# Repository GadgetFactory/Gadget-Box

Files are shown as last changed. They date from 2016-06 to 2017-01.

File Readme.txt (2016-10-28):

GadgetBox tackles the biggest problems with current IoT devices – shield stacking, easily adding hardware, hardware compatibility, and an enclosure for your project. There are lots of IoT hardware options out there but none of them have thought the problem all the way through, so what we end up with is either a crazy tower of shields or peripherals soldered on with jumper wires. Not something we can proudly show our friends and family, let alone put into use in our homes.

GadgetBox starts with a case and builds from there – so the end result is an attractive, functional device with all of the electronics safely contained in the case.

Inside the GadgetBox case is a motherboard that provides all of the circuitry to charge and use a Lipo battery pack, provide higher current to your peripherals, and organizes all IO pins into the Universal eCog scheme. A motherboard for all of the most popular IoT devices is currently in the works – Arduino, Teensy, Pi Zero, ESP8266, etc.

eCogs are Universal peripherals that just snap into the motherboard and form the top of your enclosure. Only the hardware that is needed by the end user is exposed to the outside world, everything else is tucked inside the enclosure. Because the motherboards are designed using the Universal eCog scheme you can freely interchange your eCogs between motherboards. If you have an SD card eCog shouldn’t you be able to use that same eCog with the Arduino, Teensy, Pi Zero, and ESP8266? Of course you should, the Universal eCog scheme makes that possible.

Learn more at:
https://hackaday.io/project/12426-gadgetbox-no-more-shield-stacking-or-ugly-wires
http://GadgetBox.GadgetFactory.net

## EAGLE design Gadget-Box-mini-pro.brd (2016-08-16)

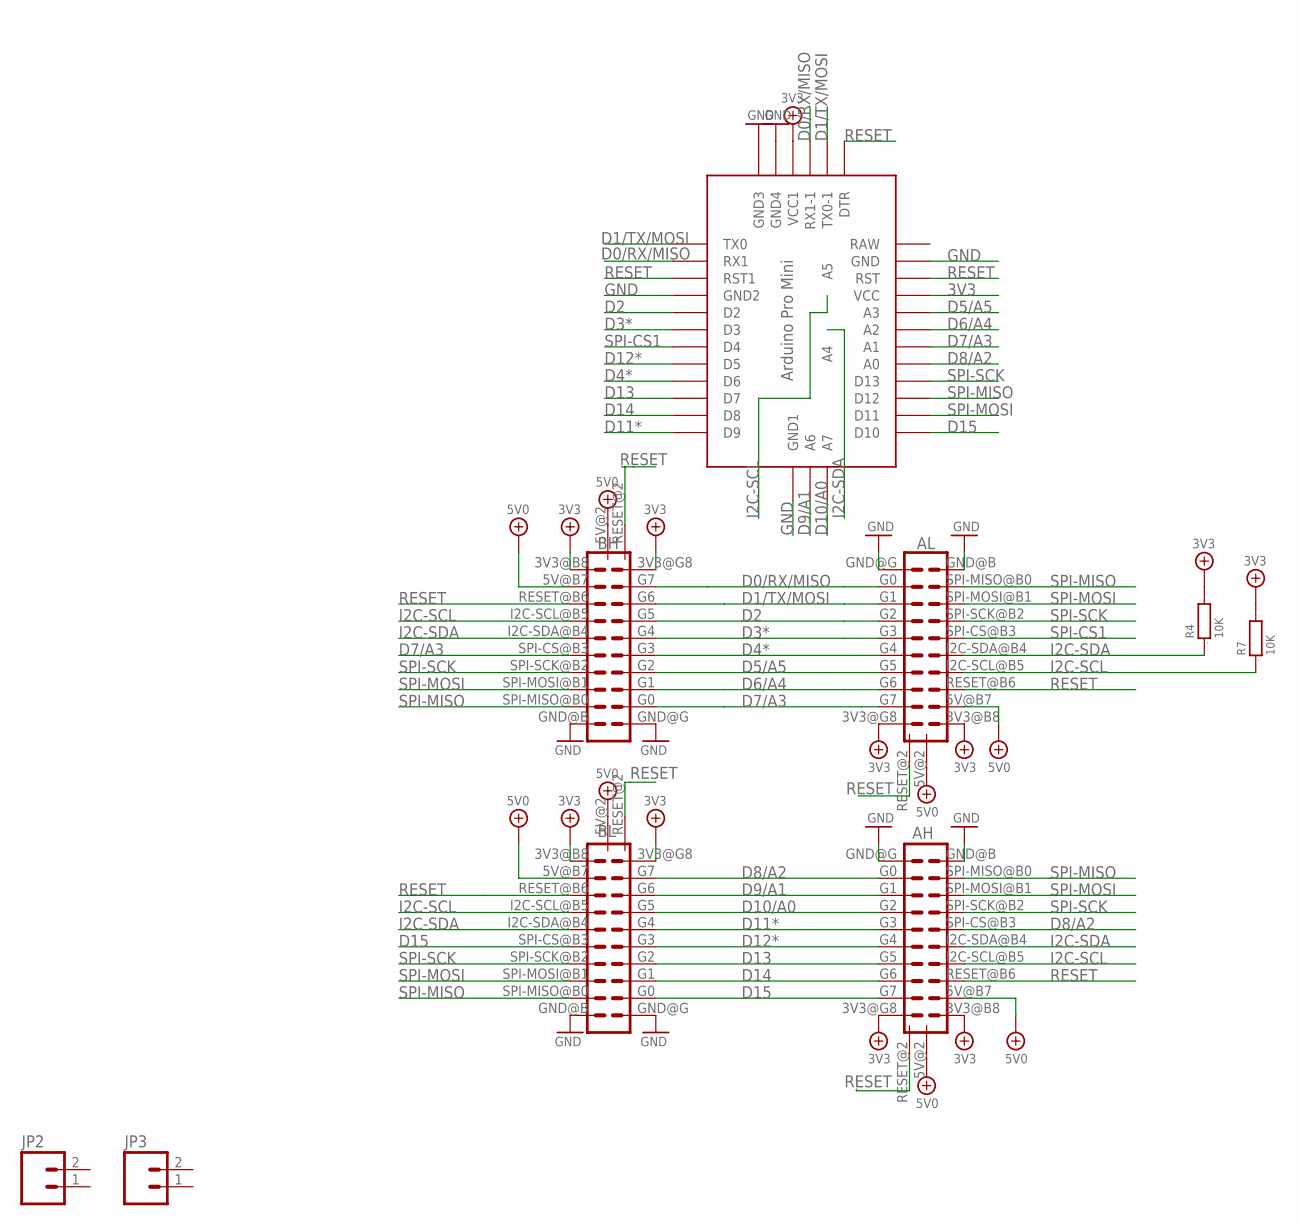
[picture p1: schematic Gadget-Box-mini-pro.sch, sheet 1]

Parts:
AH: ECOGECOG_SLOT_ALT1; ECOG_ALT1; PARTNO PPPC102LFBN-RC,SULLINS CONNECTOR SOLUTI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
AL: ECOGECOG_SLOT_ALT1; ECOG_ALT1; PARTNO PPPC102LFBN-RC,SULLINS CONNECTOR SOLUTI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
BH: ECOGECOG_SLOT_ALT1; ECOG_ALT1; PARTNO PPPC102LFBN-RC,SULLINS CONNECTOR SOLUTI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
BL: ECOGECOG_SLOT_ALT1; ECOG_ALT1; PARTNO PPPC102LFBN-RC,SULLINS CONNECTOR SOLUTI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
JP2, JP3: M021X02_NO_SILK; 1X02_NO_SILK
R4, R7: 10K; 0805
U$1: ABK-PRO-MINI

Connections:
3V3: AH.3V3@B8 (3V3), AH.3V3@G8 (3V3), AL.3V3@B8 (3V3), AL.3V3@G8 (3V3), BH.3V3@B8 (3V3), BH.3V3@G8 (3V3), BL.3V3@B8 (3V3), BL.3V3@G8 (3V3), R4.2, R7.2, U$1.VCC, U$1.VCC1; also elsewhere on the board
5V0: AH.5V@2 (5V), AH.5V@B7 (5V), AL.5V@2 (5V), AL.5V@B7 (5V), BH.5V@2 (5V), BH.5V@B7 (5V), BL.5V@2 (5V), BL.5V@B7 (5V); also elsewhere on the board
D0/RX/MISO: AL.G0, BH.G7, U$1.RX1, U$1.RX1-1
D1/TX/MOSI: AL.G1, BH.G6, U$1.TX0, U$1.TX0-1
D2: AL.G2, BH.G5, U$1.D2
D3*: AL.G3, BH.G4, U$1.D3
D4*: AL.G4, BH.G3, U$1.D6
D5/A5: AL.G5, BH.G2, U$1.A3; also elsewhere on the board
D6/A4: AL.G6, BH.G1, U$1.A2
D7/A3: AL.G7, BH.G0, BH.SPI-CS@B3 (SPI-CS), U$1.A1
D8/A2: AH.G0, AH.SPI-CS@B3 (SPI-CS), BL.G7, U$1.A0
D9/A1: AH.G1, BL.G6, U$1.A6
D10/A0: AH.G2, BL.G5, U$1.A7
D11*: AH.G3, BL.G4, U$1.D9
D12*: AH.G4, BL.G3, U$1.D5
D13: AH.G5, BL.G2, U$1.D7
D14: AH.G6, BL.G1, U$1.D8
D15: AH.G7, BL.G0, BL.SPI-CS@B3 (SPI-CS), U$1.D10
GND: AH.GND@B (GND), AH.GND@G (GND), AL.GND@B (GND), AL.GND@G (GND), BH.GND@B (GND), BH.GND@G (GND), BL.GND@B (GND), BL.GND@G (GND), U$1.GND, U$1.GND1 (GND2), U$1.GND2 (GND3), U$1.GND3 (GND4), U$1.GND4 (GND1); also elsewhere on the board
I2C-SCL: AH.I2C-SCL@B5 (I2C-SCL), AL.I2C-SCL@B5 (I2C-SCL), BH.I2C-SCL@B5 (I2C-SCL), BL.I2C-SCL@B5 (I2C-SCL), R7.1, U$1.A5
I2C-SDA: AH.I2C-SDA@B4 (I2C-SDA), AL.I2C-SDA@B4 (I2C-SDA), BH.I2C-SDA@B4 (I2C-SDA), BL.I2C-SDA@B4 (I2C-SDA), R4.1, U$1.A4
RESET: AH.RESET@2 (RESET), AH.RESET@B6 (RESET), AL.RESET@2 (RESET), AL.RESET@B6 (RESET), BH.RESET@2 (RESET), BH.RESET@B6 (RESET), BL.RESET@2 (RESET), BL.RESET@B6 (RESET), U$1.DTR, U$1.RST, U$1.RST1
SPI-CS1: AL.SPI-CS@B3 (SPI-CS), U$1.D4
SPI-MISO: AH.SPI-MISO@B0 (SPI-MISO), AL.SPI-MISO@B0 (SPI-MISO), BH.SPI-MISO@B0 (SPI-MISO), BL.SPI-MISO@B0 (SPI-MISO), U$1.D12
SPI-MOSI: AH.SPI-MOSI@B1 (SPI-MOSI), AL.SPI-MOSI@B1 (SPI-MOSI), BH.SPI-MOSI@B1 (SPI-MOSI), BL.SPI-MOSI@B1 (SPI-MOSI), U$1.D11
SPI-SCK: AH.SPI-SCK@B2 (SPI-SCK), AL.SPI-SCK@B2 (SPI-SCK), BH.SPI-SCK@B2 (SPI-SCK), BL.SPI-SCK@B2 (SPI-SCK), U$1.D13

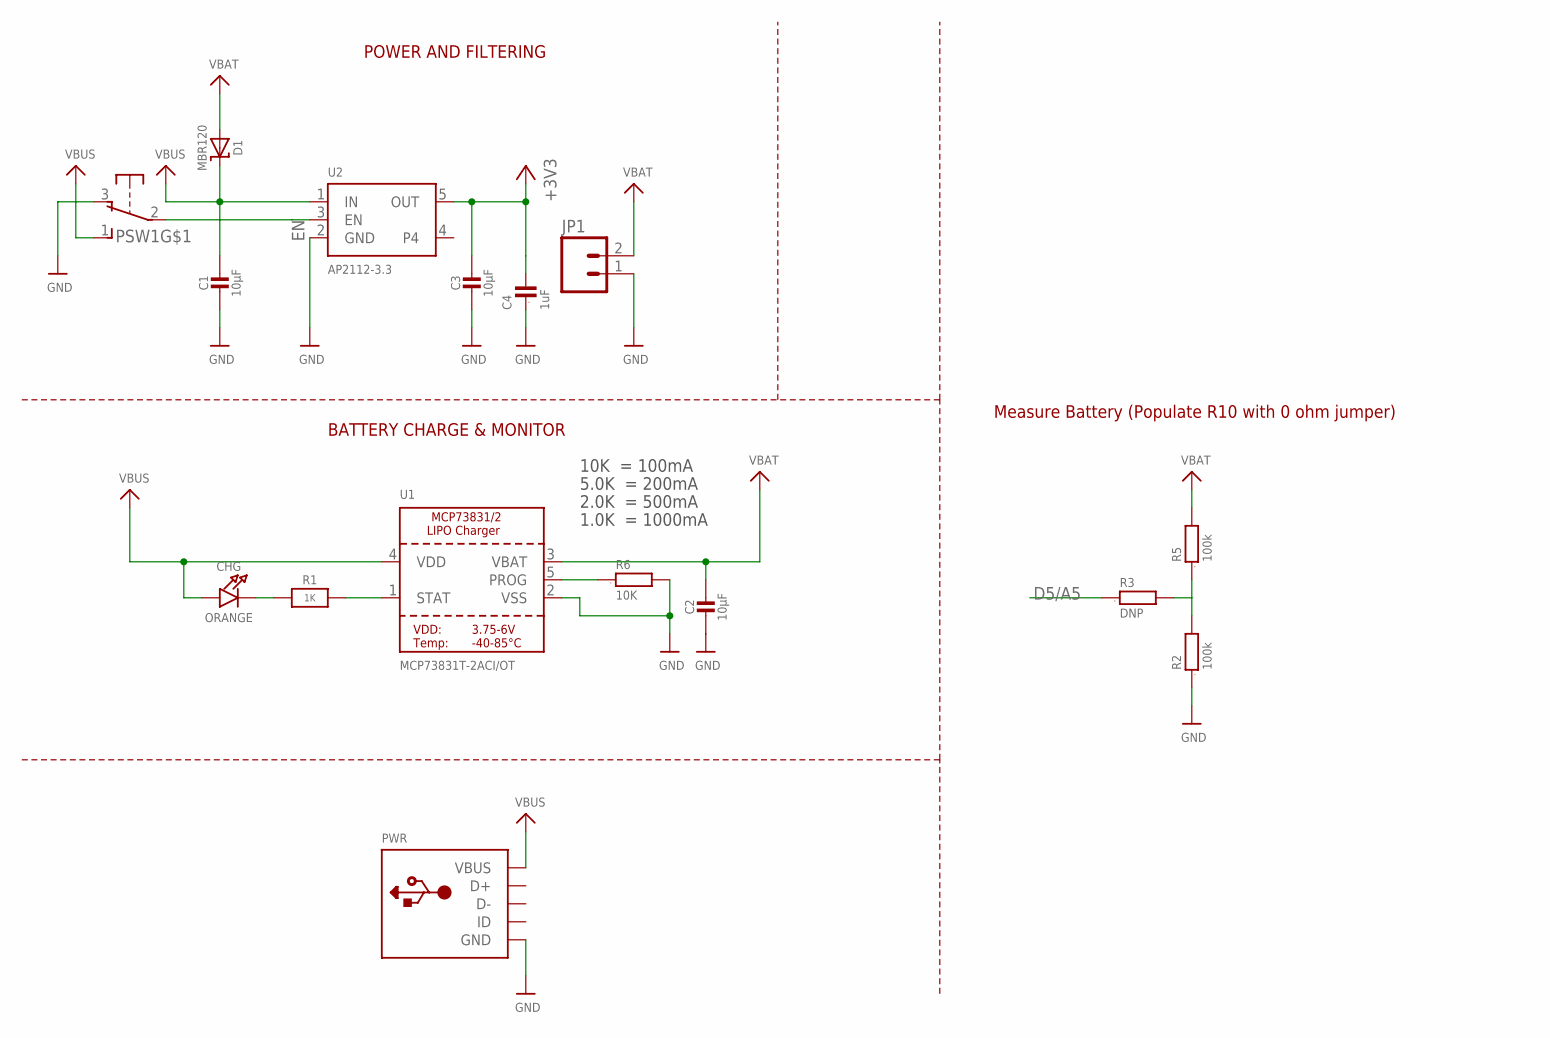
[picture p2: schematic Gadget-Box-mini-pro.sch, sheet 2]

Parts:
C1, C2, C3: 10µF; 0805-NO; PARTNO CL21F106ZPFNNNE,Samsung,DK,1276-3012-1-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
C4: 1uF; 0603; PARTNO C1608X5R1A105K080AC,TDK CORPORATION (VA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
CHG: ORANGE; CHIPLED_0805_NOOUTLINE; PARTNO LTST-C171EKT,LITE-ON INC (VA),DK,160-14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
D1: MBR120; SOD-123; PARTNO MBR120VLSFT3G,on semiconductor,dk,MBR12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
JP1: M02-JST-2-PTH-NO_SILK; JST-2-PTH-NS
PSW1: OS102011MA1Q; PARTNO OS102011MA1QN1,C&K Components,dk,CKN955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
PWR: USBMINIB; USB-MINIB
R1: 1K; 0603-NO; PARTNO RC0603JR-071KL,YAGEO (VA),dk,311-1.0KGR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
R2, R5: 100k; 0603; PARTNO RC0603JR-07100KL,YAGEO (VA),dk,311-100K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
R3: DNP; 0603
R6: 10K; 0603; PARTNO RC0603JR-0710KL,YAGEO (VA),dk,311-10KGR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
U1: MCP73831T-2ACI/OT; SOT23-5; PARTNO MCP73831T-2ACI/OT,MICROCHIP TECHNOLOGY 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
U2: AP2112-3.3; SOT23-5; PARTNO AP2112K-3.3TRG1,Diodes Incorporated,dk,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

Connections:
3V3: C3.1, C4.2, U2.5 (OUT); also elsewhere on the board
5V0: C1.1, CHG.A, D1.C, PSW1.1 (S), PWR.VBUS, U1.4 (VDD), U2.1 (IN); also elsewhere on the board
D5/A5: R3.1; also elsewhere on the board
EN: PSW1.2, U2.3 (EN)
GND: C1.2, C2.2, C3.2, C4.1, JP1.1, PSW1.3 (O), PWR.GND, R2.1, R6.2, U1.2 (VSS), U2.2 (GND); also elsewhere on the board
unnamed: CHG.C, R1.1
unnamed: R2.2, R3.2, R5.1
unnamed: R1.2, U1.1 (STAT)
unnamed: R6.1, U1.5 (PROG)
VBAT: C2.1, D1.A, JP1.2, R5.2, U1.3 (VBAT)

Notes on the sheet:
POWER AND FILTERING
10K = 100mA
5.0K = 200mA
2.0K = 500mA
1.0K = 1000mA
BATTERY CHARGE & MONITOR
Measure Battery (Populate R10 with 0 ohm jumper)

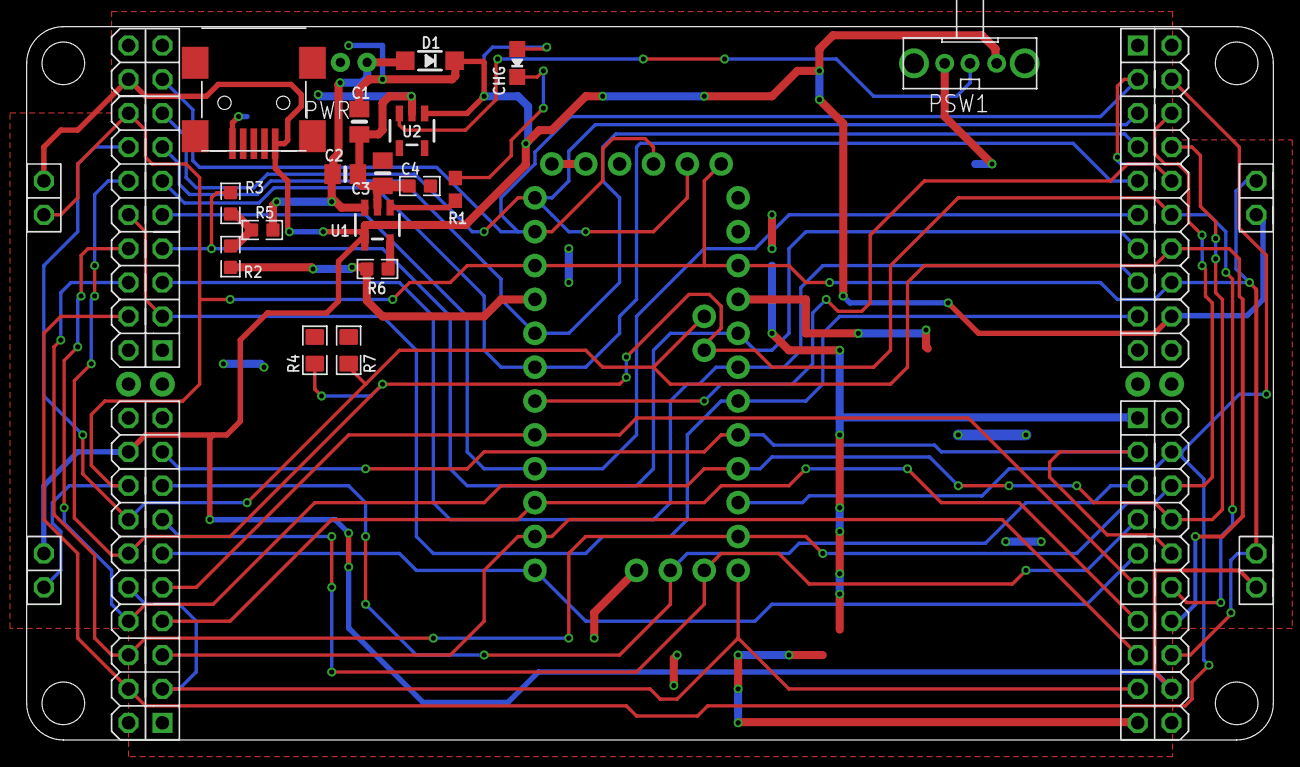
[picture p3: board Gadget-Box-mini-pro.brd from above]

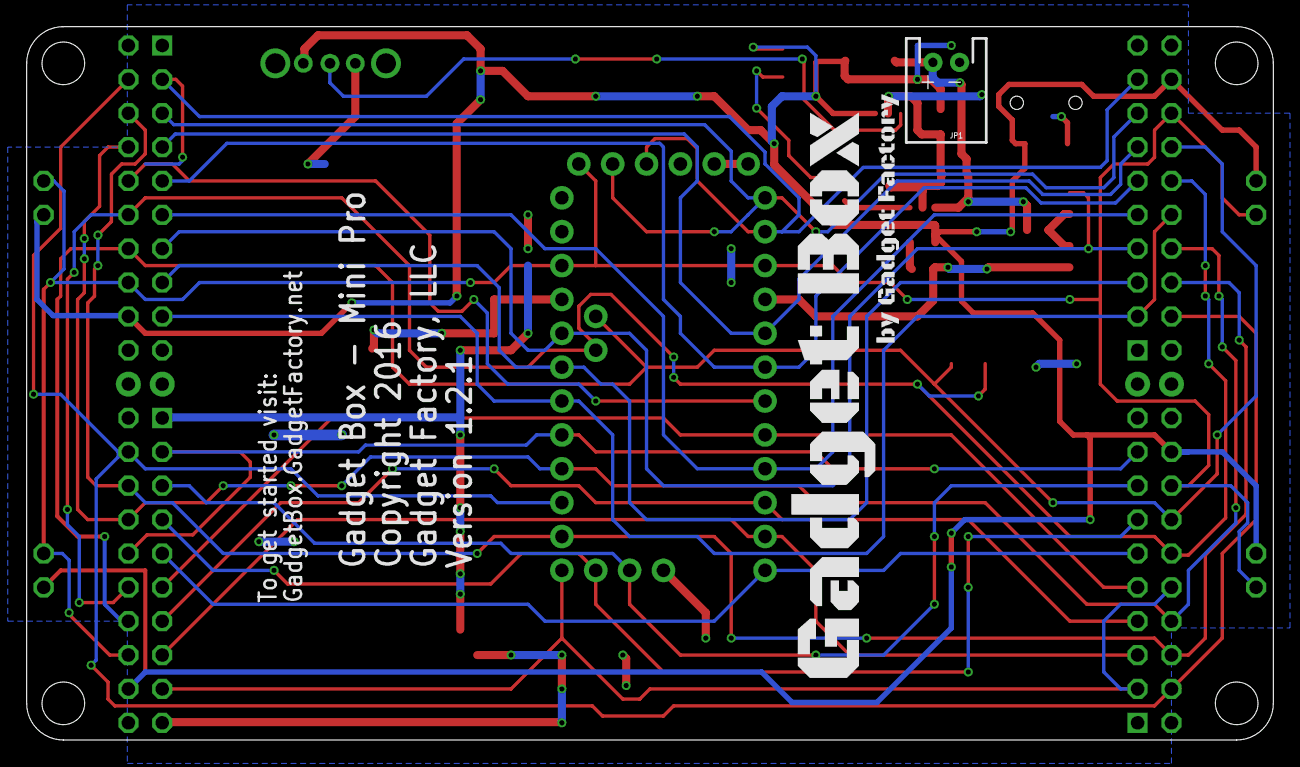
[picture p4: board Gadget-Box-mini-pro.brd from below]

Board: 2 copper layers, 93.5 x 53.5 mm, 27 parts (2 on the bottom side), 32 nets.

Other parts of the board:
$$U$1: ECOG93P53P5
U$100: GADGETBOX_TEXT

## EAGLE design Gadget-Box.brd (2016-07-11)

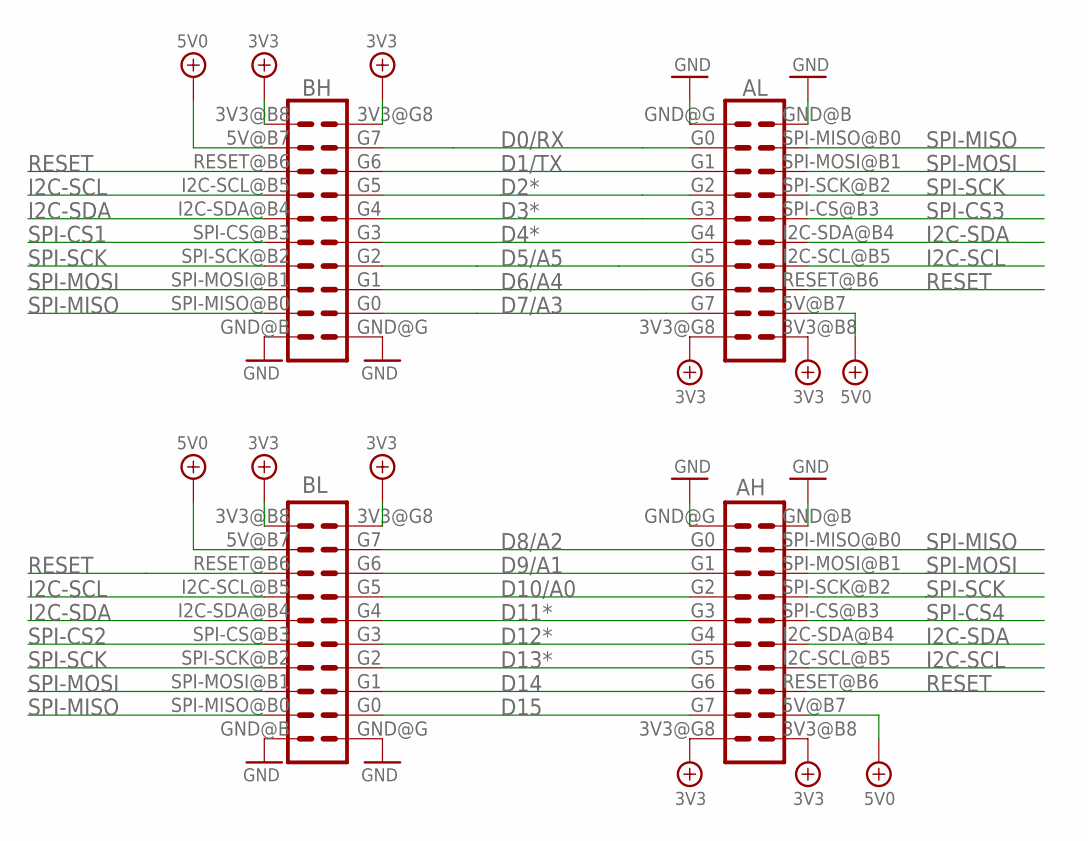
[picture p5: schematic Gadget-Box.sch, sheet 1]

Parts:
AH: ECOGECOG_SLOT; ECOG; PARTNO PPPC102LFBN-RC,SULLINS CONNECTOR SOLUTI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
AL: ECOGECOG_SLOT; ECOG; PARTNO PPPC102LFBN-RC,SULLINS CONNECTOR SOLUTI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
BH: ECOGECOG_SLOT; ECOG; PARTNO PPPC102LFBN-RC,SULLINS CONNECTOR SOLUTI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
BL: ECOGECOG_SLOT; ECOG; PARTNO PPPC102LFBN-RC,SULLINS CONNECTOR SOLUTI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

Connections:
3V3: AH.3V3@B8 (3V3), AH.3V3@G8 (3V3), AL.3V3@B8 (3V3), AL.3V3@G8 (3V3), BH.3V3@B8 (3V3), BH.3V3@G8 (3V3), BL.3V3@B8 (3V3), BL.3V3@G8 (3V3); also elsewhere on the board
D0/RX: AL.G0, BH.G7; also elsewhere on the board
D1/TX: AL.G1, BH.G6; also elsewhere on the board
D2*: AL.G2, BH.G5; also elsewhere on the board
D3*: AL.G3, BH.G4; also elsewhere on the board
D4*: AL.G4, BH.G3; also elsewhere on the board
D5/A5: AL.G5, BH.G2; also elsewhere on the board
D6/A4: AL.G6, BH.G1; also elsewhere on the board
D7/A3: AL.G7, BH.G0; also elsewhere on the board
D8/A2: AH.G0, BL.G7; also elsewhere on the board
D9/A1: AH.G1, BL.G6; also elsewhere on the board
D10/A0: AH.G2, BL.G5; also elsewhere on the board
D11*: AH.G3, BL.G4; also elsewhere on the board
D12*: AH.G4, BL.G3; also elsewhere on the board
D13*: AH.G5, BL.G2; also elsewhere on the board
D14: AH.G6, BL.G1; also elsewhere on the board
D15: AH.G7, BL.G0; also elsewhere on the board
GND: AH.GND@B (GND), AH.GND@G (GND), AL.GND@B (GND), AL.GND@G (GND), BH.GND@B (GND), BH.GND@G (GND), BL.GND@B (GND), BL.GND@G (GND); also elsewhere on the board
I2C-SCL: AH.I2C-SCL@B5 (I2C-SCL), AL.I2C-SCL@B5 (I2C-SCL), BH.I2C-SCL@B5 (I2C-SCL), BL.I2C-SCL@B5 (I2C-SCL); also elsewhere on the board
I2C-SDA: AH.I2C-SDA@B4 (I2C-SDA), AL.I2C-SDA@B4 (I2C-SDA), BH.I2C-SDA@B4 (I2C-SDA), BL.I2C-SDA@B4 (I2C-SDA); also elsewhere on the board
RESET: AH.RESET@B6 (RESET), AL.RESET@B6 (RESET), BH.RESET@B6 (RESET), BL.RESET@B6 (RESET); also elsewhere on the board
SPI-CS1: BH.SPI-CS@B3 (SPI-CS); also elsewhere on the board
SPI-CS2: BL.SPI-CS@B3 (SPI-CS); also elsewhere on the board
SPI-CS3: AL.SPI-CS@B3 (SPI-CS); also elsewhere on the board
SPI-CS4: AH.SPI-CS@B3 (SPI-CS); also elsewhere on the board
SPI-MISO: AH.SPI-MISO@B0 (SPI-MISO), AL.SPI-MISO@B0 (SPI-MISO), BH.SPI-MISO@B0 (SPI-MISO), BL.SPI-MISO@B0 (SPI-MISO); also elsewhere on the board
SPI-MOSI: AH.SPI-MOSI@B1 (SPI-MOSI), AL.SPI-MOSI@B1 (SPI-MOSI), BH.SPI-MOSI@B1 (SPI-MOSI), BL.SPI-MOSI@B1 (SPI-MOSI); also elsewhere on the board
SPI-SCK: AH.SPI-SCK@B2 (SPI-SCK), AL.SPI-SCK@B2 (SPI-SCK), BH.SPI-SCK@B2 (SPI-SCK), BL.SPI-SCK@B2 (SPI-SCK); also elsewhere on the board
VBUS: AH.5V@B7 (5V), AL.5V@B7 (5V), BH.5V@B7 (5V), BL.5V@B7 (5V); also elsewhere on the board

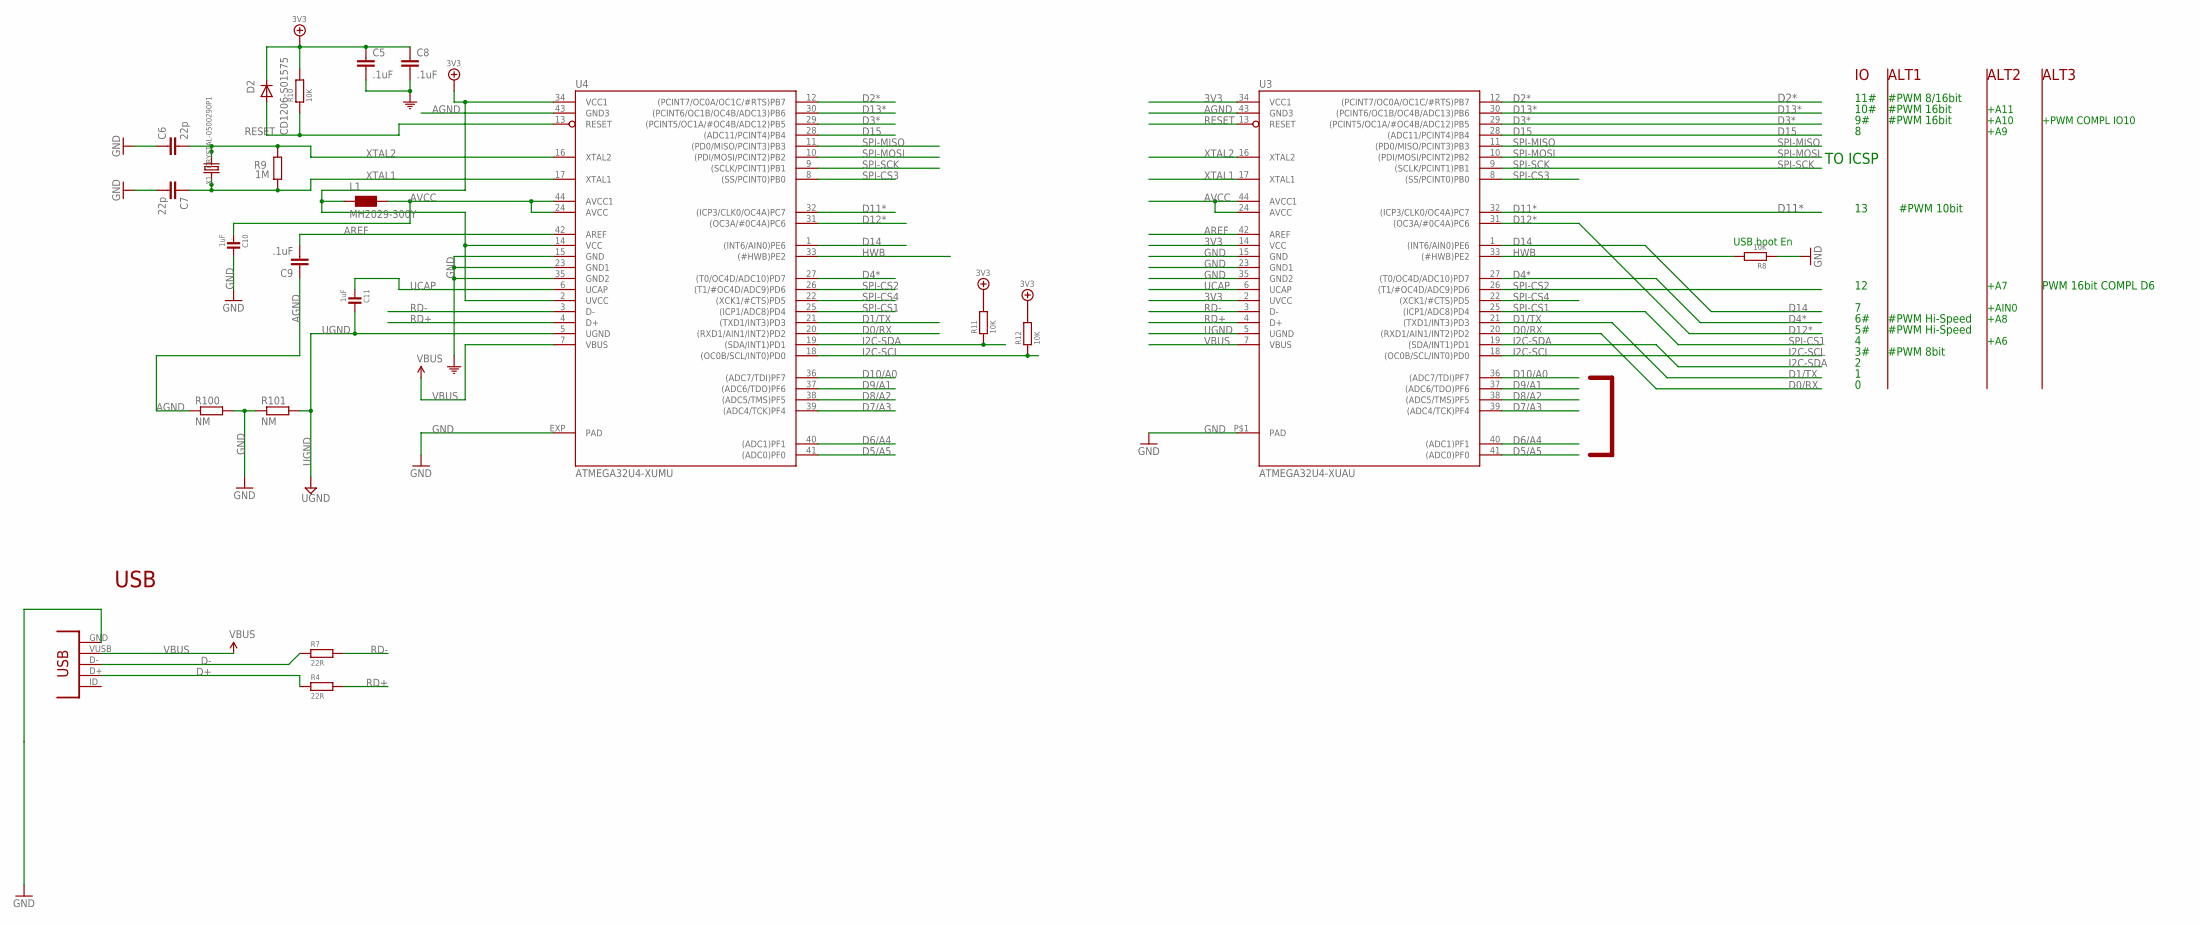
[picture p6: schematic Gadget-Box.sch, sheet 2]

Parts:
C5, C8, C9: .1uF; C0603-ROUND; PARTNO GRM188F51E104ZA01D,MURATA ELECTRONICS (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
C6, C7: 22p; C0603-ROUND; PARTNO C1608C0G1H220J080AA,TDK CORPORATION (VA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
C10, C11: 1uF; 0603; PARTNO C1608X5R1A105K080AC,TDK CORPORATION (VA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
D2: CD1206-S01575; MINIMELF; PARTNO CD1206-S01575,BOURNS INC (VA),dk,CD1206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
L1: MH2029-300Y; 0805; PARTNO MH2029-300Y,BOURNS INC (VA),dk,MH2029-3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
R4, R7: 22R; 0805; PARTNO RMCF0805JT22R0,STACKPOLE ELECTRONICS IN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
R8, R10, R11, R12: 10K; 0603; PARTNO RC0603JR-0710KL,YAGEO (VA),dk,311-10KGR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
R9: 1M; R0603-ROUND; PARTNO RMCF0603JT1M00,STACKPOLE ELECTRONICS IN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
R100, R101: NM; R0402
U3: ATMEGA32U4-XUAU; TQFP44-PAD; PARTNO ATMEGA32U4-AUR,ATMEL (VA),dk,ATMEGA32U4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
U4: ATMEGA32U4-XUMU; QFN44ML7X7
USB: CONN_USB; CONN_USB_MINI-B; PARTNO USB-M26FTR,ON SHORE TECHNOLOGY INC (VA)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
X1: CRYSTAL-0500290P1; 2P-SMD-5.0X3.2; PARTNO ABM3-8.000MHZ-D2Y-T,Abracon Corporation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

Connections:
3V3: C5.1, C8.1, D2.C, L1.1, R10.2, R11.2, R12.2, U3.2 (UVCC), U3.14 (VCC), U3.34 (VCC1), U4.2 (UVCC), U4.14 (VCC), U4.34 (VCC1); also elsewhere on the board
AGND: C9.1, R100.1, U3.43 (GND3), U4.43 (GND3)
AREF: C9.2, U3.42 (AREF), U4.42 (AREF)
AVCC: C10.1, L1.2, U3.24 (AVCC), U3.44 (AVCC1), U4.24 (AVCC), U4.44 (AVCC1)
D0/RX: U3.20 ((RXD1/AIN1/INT2)PD2), U4.20 ((RXD1/AIN1/INT2)PD2); also elsewhere on the board
D1/TX: U3.21 ((TXD1/INT3)PD3), U4.21 ((TXD1/INT3)PD3); also elsewhere on the board
D2*: U3.12 ((PCINT7/OC0A/OC1C/#RTS)PB7), U4.12 ((PCINT7/OC0A/OC1C/#RTS)PB7); also elsewhere on the board
D3*: U3.29 ((PCINT5/OC1A/#OC4B/ADC12)PB5), U4.29 ((PCINT5/OC1A/#OC4B/ADC12)PB5); also elsewhere on the board
D4*: U3.27 ((T0/OC4D/ADC10)PD7), U4.27 ((T0/OC4D/ADC10)PD7); also elsewhere on the board
D5/A5: U3.41 ((ADC0)PF0), U4.41 ((ADC0)PF0); also elsewhere on the board
D6/A4: U3.40 ((ADC1)PF1), U4.40 ((ADC1)PF1); also elsewhere on the board
D7/A3: U3.39 ((ADC4/TCK)PF4), U4.39 ((ADC4/TCK)PF4); also elsewhere on the board
D8/A2: U3.38 ((ADC5/TMS)PF5), U4.38 ((ADC5/TMS)PF5); also elsewhere on the board
D9/A1: U3.37 ((ADC6/TDO)PF6), U4.37 ((ADC6/TDO)PF6); also elsewhere on the board
D10/A0: U3.36 ((ADC7/TDI)PF7), U4.36 ((ADC7/TDI)PF7); also elsewhere on the board
D11*: U3.32 ((ICP3/CLK0/OC4A)PC7), U4.32 ((ICP3/CLK0/OC4A)PC7); also elsewhere on the board
D12*: U3.31 ((OC3A/#0C4A)PC6), U4.31 ((OC3A/#0C4A)PC6); also elsewhere on the board
D13*: U3.30 ((PCINT6/OC1B/OC4B/ADC13)PB6), U4.30 ((PCINT6/OC1B/OC4B/ADC13)PB6); also elsewhere on the board
D14: U3.1 ((INT6/AIN0)PE6), U4.1 ((INT6/AIN0)PE6); also elsewhere on the board
D15: U3.28 ((ADC11/PCINT4)PB4), U4.28 ((ADC11/PCINT4)PB4); also elsewhere on the board
D+: R4.1, USB.D+
D-: R7.1, USB.D-
GND: C5.2, C6.1, C7.2, C8.2, C10.2, R8.1, R100.2, R101.1, U3.15 (GND), U3.23 (GND1), U3.35 (GND2), U3.P$1 (PAD), U4.15 (GND), U4.23 (GND1), U4.35 (GND2), U4.EXP (PAD), USB.GND; also elsewhere on the board
HWB: R8.2, U3.33 ((#HWB)PE2), U4.33 ((#HWB)PE2)
I2C-SCL: R12.1, U3.18 ((OC0B/SCL/INT0)PD0), U4.18 ((OC0B/SCL/INT0)PD0); also elsewhere on the board
I2C-SDA: R11.1, U3.19 ((SDA/INT1)PD1), U4.19 ((SDA/INT1)PD1); also elsewhere on the board
RD+: R4.2, U3.4 (D+), U4.4 (D+)
RD-: R7.2, U3.3 (D-), U4.3 (D-)
RESET: D2.A, R10.1, U3.13 (RESET), U4.13 (RESET); also elsewhere on the board
SPI-CS1: U3.25 ((ICP1/ADC8)PD4), U4.25 ((ICP1/ADC8)PD4); also elsewhere on the board
SPI-CS2: U3.26 ((T1/#OC4D/ADC9)PD6), U4.26 ((T1/#OC4D/ADC9)PD6); also elsewhere on the board
SPI-CS3: U3.8 ((SS/PCINT0)PB0), U4.8 ((SS/PCINT0)PB0); also elsewhere on the board
SPI-CS4: U3.22 ((XCK1/#CTS)PD5), U4.22 ((XCK1/#CTS)PD5); also elsewhere on the board
SPI-MISO: U3.11 ((PD0/MISO/PCINT3)PB3), U4.11 ((PD0/MISO/PCINT3)PB3); also elsewhere on the board
SPI-MOSI: U3.10 ((PDI/MOSI/PCINT2)PB2), U4.10 ((PDI/MOSI/PCINT2)PB2); also elsewhere on the board
SPI-SCK: U3.9 ((SCLK/PCINT1)PB1), U4.9 ((SCLK/PCINT1)PB1); also elsewhere on the board
UCAP: C11.1, U3.6 (UCAP), U4.6 (UCAP)
UGND: C11.2, R101.2, U3.5 (UGND), U4.5 (UGND)
VBUS: U3.7 (VBUS), U4.7 (VBUS), USB.VUSB; also elsewhere on the board
XTAL1: C7.1, R9.1, U3.17 (XTAL1), U4.17 (XTAL1), X1.1
XTAL2: C6.2, R9.2, U3.16 (XTAL2), U4.16 (XTAL2), X1.2

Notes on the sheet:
USB boot En
USB
TO ICSP
10#
11#
#PWM 8bit
#PWM Hi-Speed
#PWM 8/16bit
#PWM 16bit
PWM 16bit COMPL D6
#PWM 10bit
+A6
+A7
+A11
+A10
+A8
+A9
+PWM COMPL IO10
+AIN0
ALT1
ALT2
ALT3

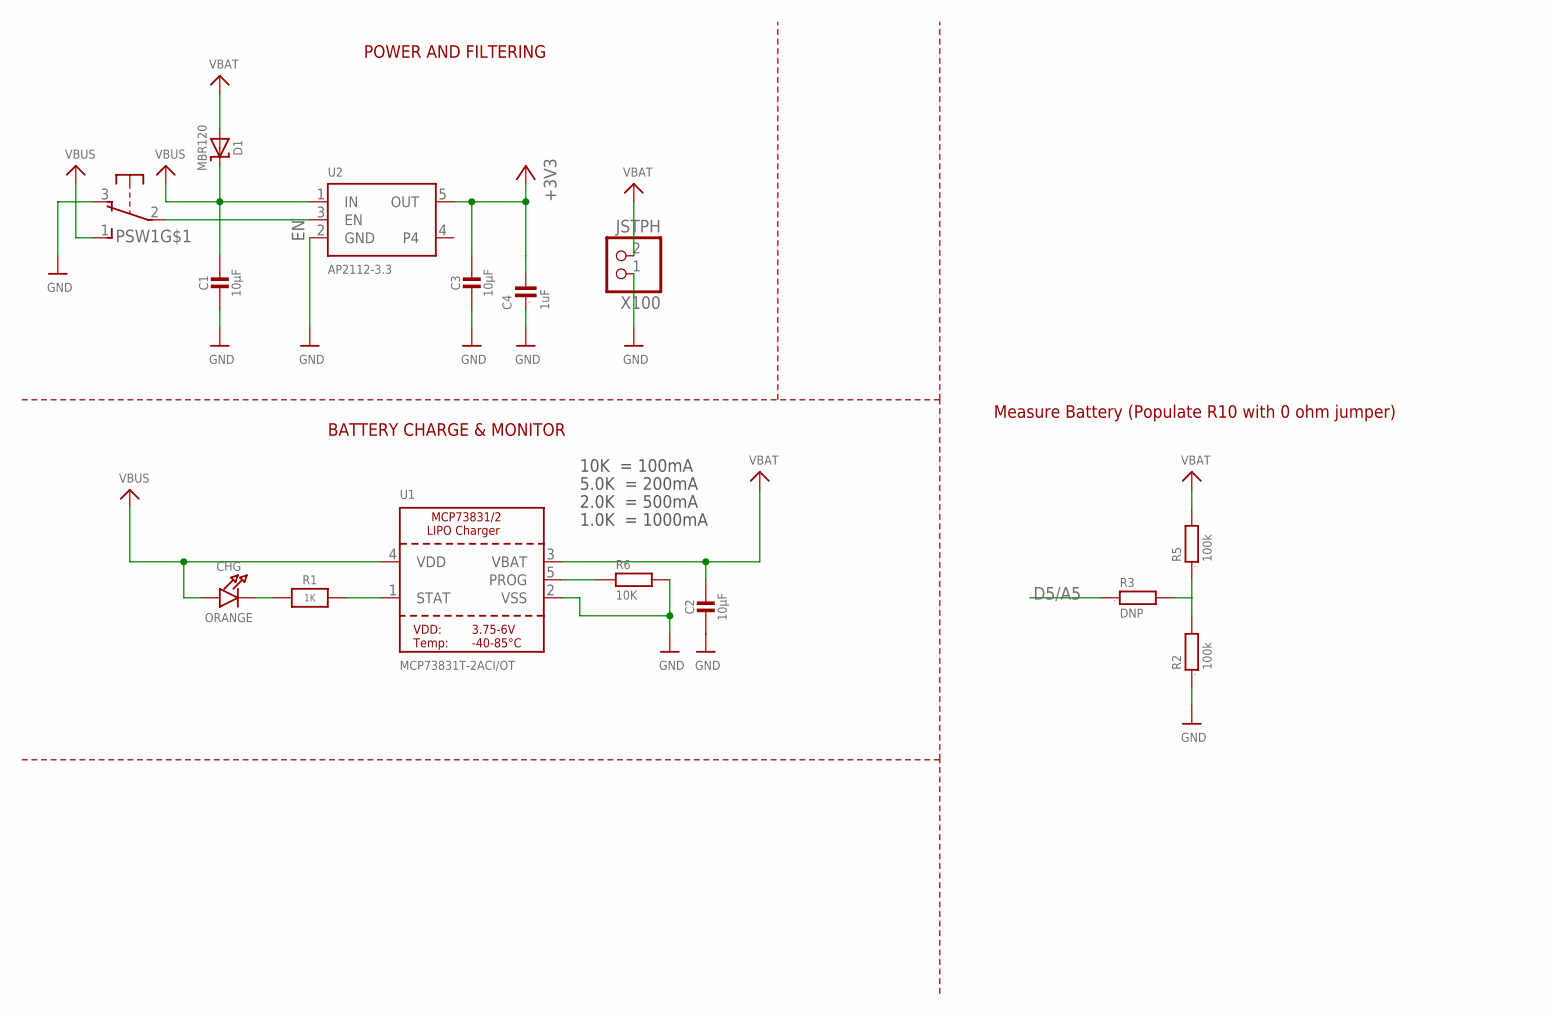
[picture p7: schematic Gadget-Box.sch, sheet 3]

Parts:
C1, C2, C3: 10µF; 0805-NO; PARTNO CL21F106ZPFNNNE,Samsung,DK,1276-3012-1-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
C4: 1uF; 0603; PARTNO C1608X5R1A105K080AC,TDK CORPORATION (VA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
CHG: ORANGE; CHIPLED_0805_NOOUTLINE; PARTNO LTST-C171EKT,LITE-ON INC (VA),DK,160-14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
D1: MBR120; SOD-123; PARTNO MBR120VLSFT3G,on semiconductor,dk,MBR12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
PSW1: OS102011MA1Q; PARTNO OS102011MA1QN1,C&K Components,dk,CKN955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
R1: 1K; 0603-NO; PARTNO RC0603JR-071KL,YAGEO (VA),dk,311-1.0KGR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
R2, R5: 100k; 0603; PARTNO RC0603JR-07100KL,YAGEO (VA),dk,311-100K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
R3: DNP; 0603
R6: 10K; 0603; PARTNO RC0603JR-0710KL,YAGEO (VA),dk,311-10KGR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
U1: MCP73831T-2ACI/OT; SOT23-5; PARTNO MCP73831T-2ACI/OT,MICROCHIP TECHNOLOGY 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
U2: AP2112-3.3; SOT23-5; PARTNO AP2112K-3.3TRG1,Diodes Incorporated,dk,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
X100: JSTPH; JSTPH2; PARTNO S2B-PH-SM4-TB(LF)(SN),JST SALES AMERICA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

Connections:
3V3: C3.1, C4.2, U2.5 (OUT); also elsewhere on the board
D5/A5: R3.1; also elsewhere on the board
EN: PSW1.2, U2.3 (EN)
GND: C1.2, C2.2, C3.2, C4.1, PSW1.3 (O), R2.1, R6.2, U1.2 (VSS), U2.2 (GND), X100.1; also elsewhere on the board
unnamed: CHG.C, R1.1
unnamed: R2.2, R3.2, R5.1
unnamed: R1.2, U1.1 (STAT)
unnamed: R6.1, U1.5 (PROG)
VBAT: C2.1, D1.A, R5.2, U1.3 (VBAT), X100.2
VBUS: C1.1, CHG.A, D1.C, PSW1.1 (S), U1.4 (VDD), U2.1 (IN); also elsewhere on the board

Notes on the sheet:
POWER AND FILTERING
10K = 100mA
5.0K = 200mA
2.0K = 500mA
1.0K = 1000mA
BATTERY CHARGE & MONITOR
Measure Battery (Populate R10 with 0 ohm jumper)

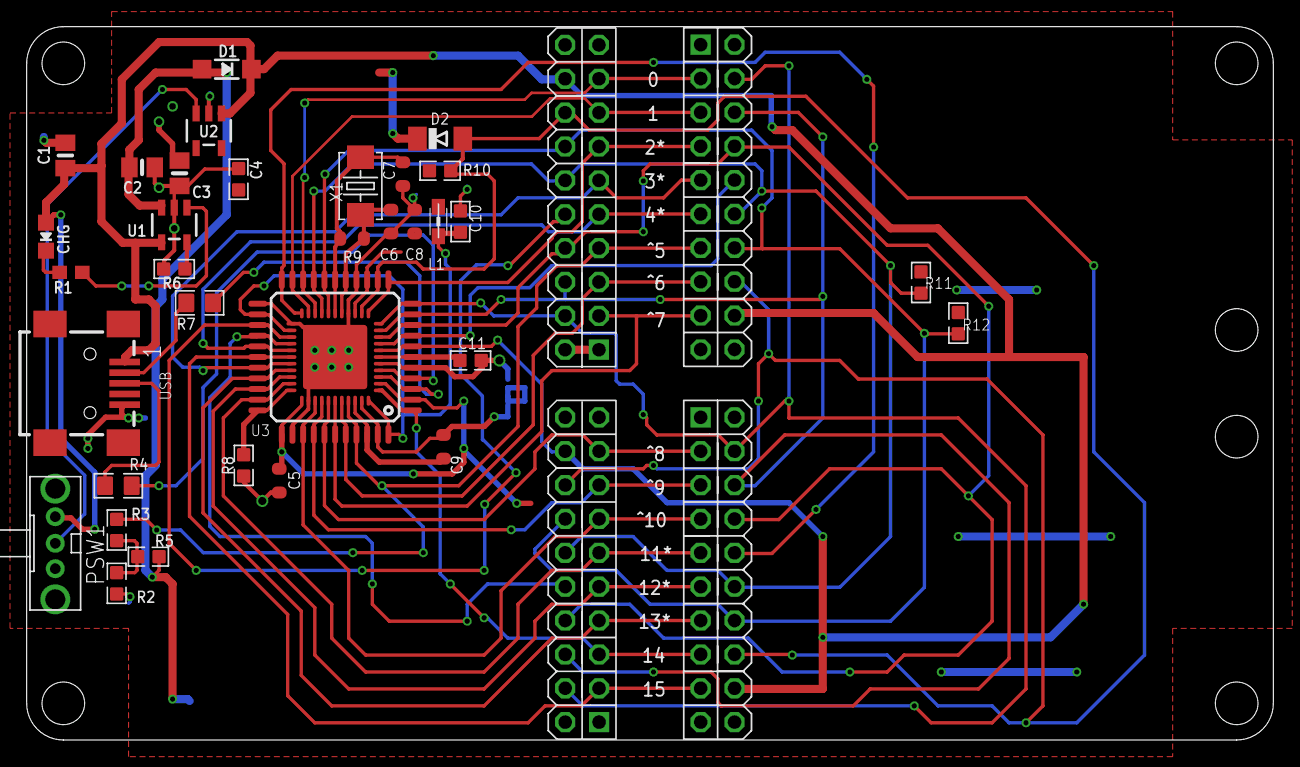
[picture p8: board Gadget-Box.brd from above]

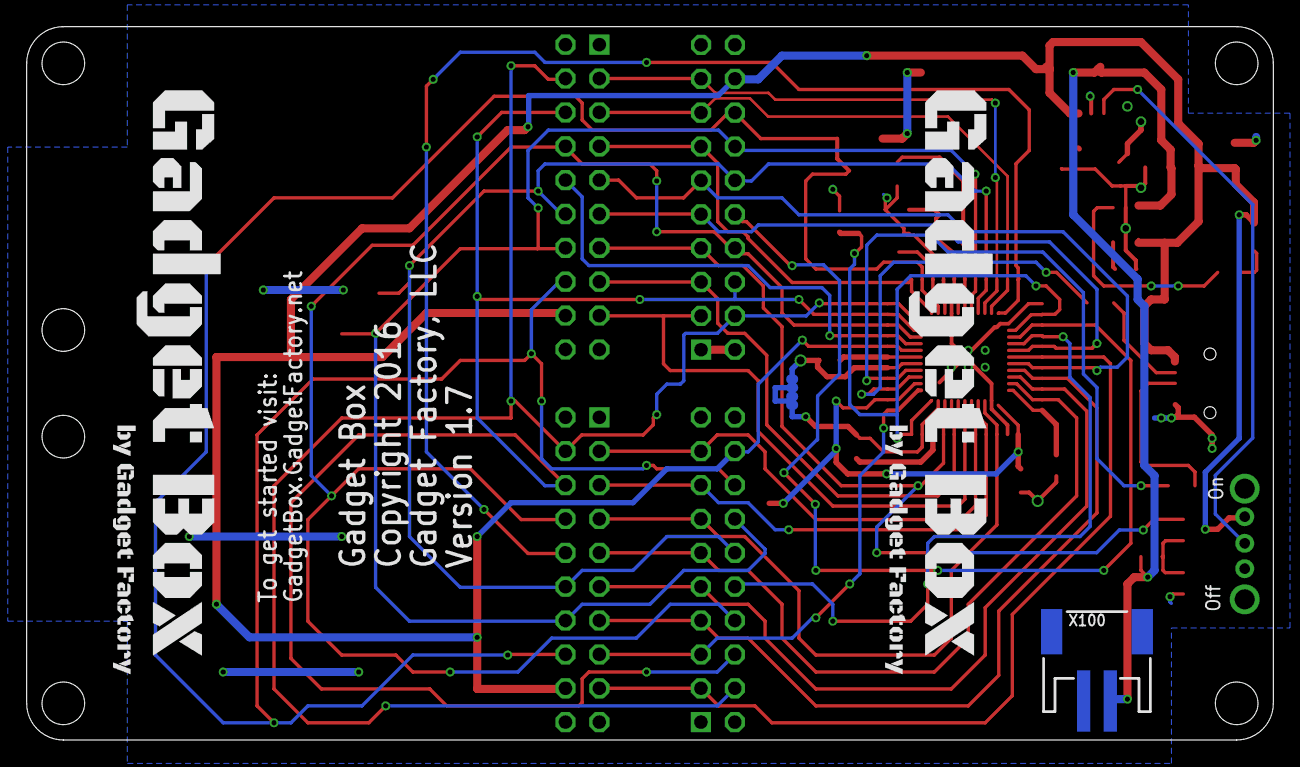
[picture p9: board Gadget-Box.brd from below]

Board: 2 copper layers, 93.5 x 53.5 mm, 44 parts (5 on the bottom side), 47 nets.

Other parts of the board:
$$U$1: ECOG93P53P5
U$100, U$101: GADGETBOX_TEXT

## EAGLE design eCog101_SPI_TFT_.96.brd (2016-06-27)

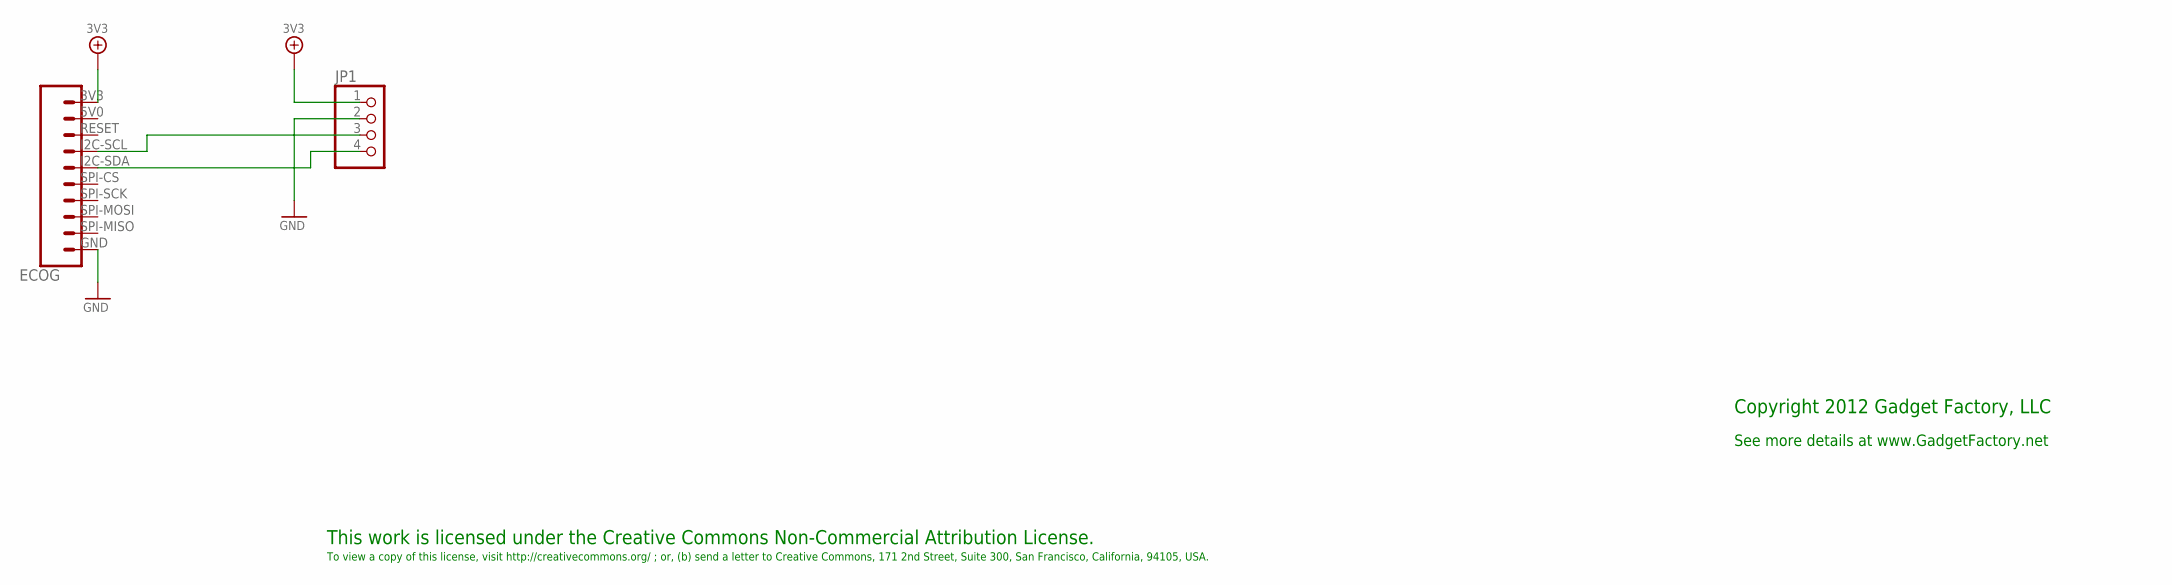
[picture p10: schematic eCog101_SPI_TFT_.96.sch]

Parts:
ECOG: ECOG_BUSES_ROWECOG_BUSES_SMD; ECOG_BUSES_SMD
JP1: PINHD-1X4; 1X04

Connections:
3V3: ECOG.3V3, JP1.1
GND: ECOG.GND, JP1.2
unnamed: ECOG.I2C-SCL, JP1.3
unnamed: ECOG.I2C-SDA, JP1.4

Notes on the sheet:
This work is licensed under the Creative Commons Non-Commercial Attribution License.
To view a copy of this license, visit http://creativecommons.org/ ; or, (b) send a letter to Creative Commons, 171 2nd Street, Suite 300, San Francisco, California, 94105, USA.
Copyright 2012 Gadget Factory, LLC
See more details at www.GadgetFactory.net

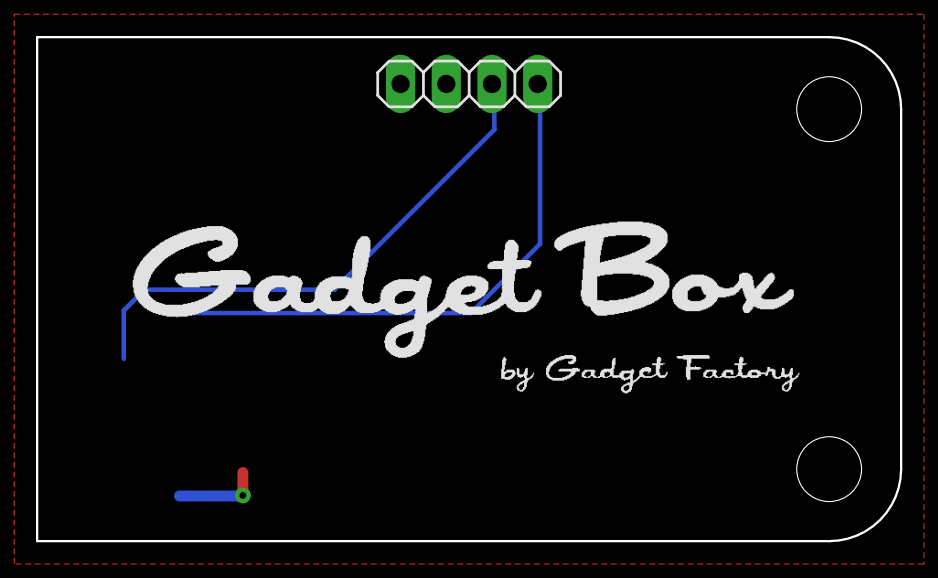
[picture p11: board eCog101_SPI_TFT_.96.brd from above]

Board: 2 copper layers, 48.0 x 28.0 mm, 3 parts (0 on the bottom side), 4 nets.

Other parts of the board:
U$1: GADGETBOX_TEXT

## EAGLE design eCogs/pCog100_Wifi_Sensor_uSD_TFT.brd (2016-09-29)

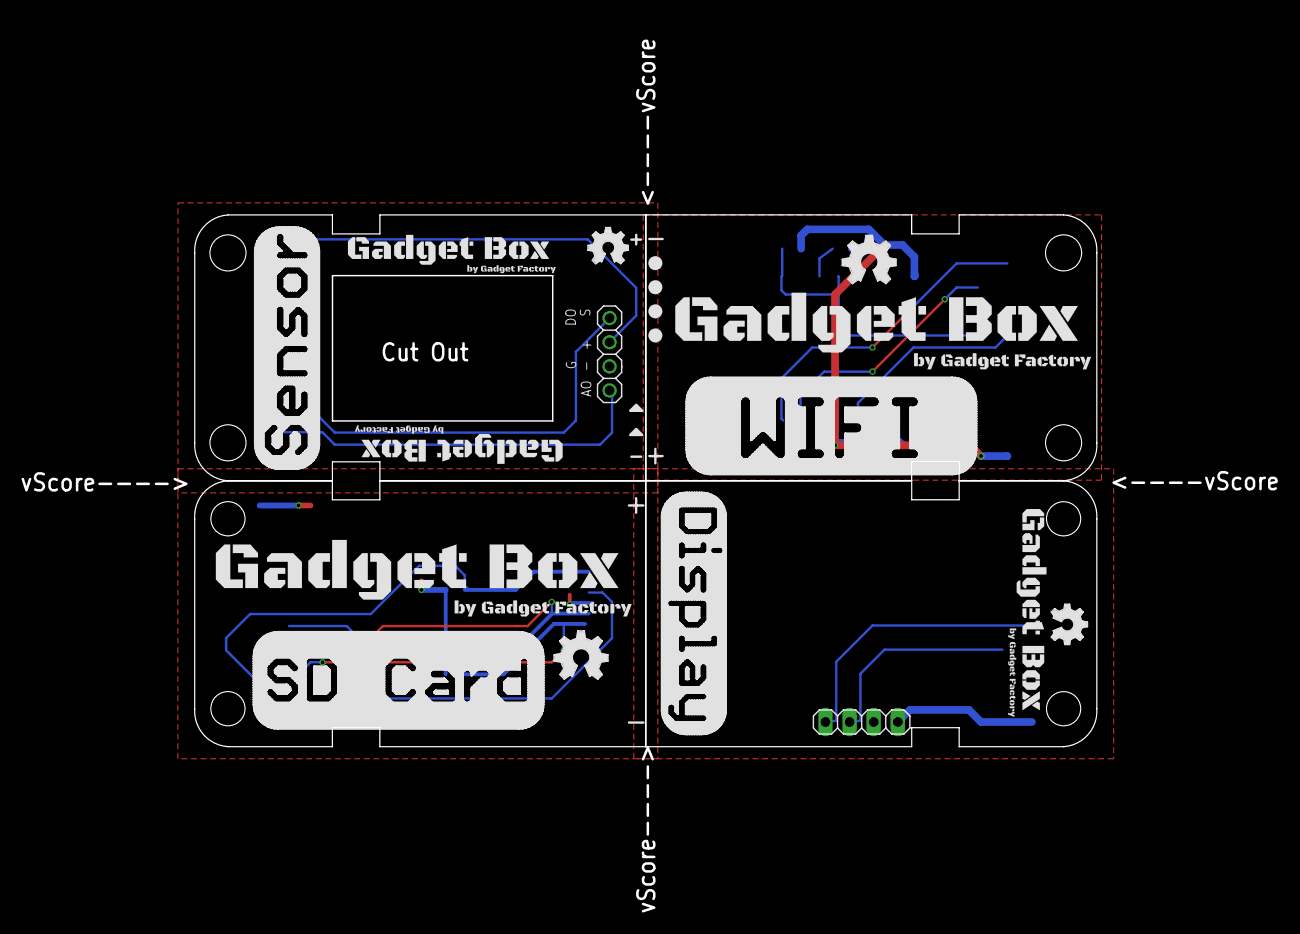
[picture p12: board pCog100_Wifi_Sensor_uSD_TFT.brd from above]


Board: 2 copper layers, 95.0 x 56.0 mm, 30 parts (9 on the bottom side), 17 nets.

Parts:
ECOG, ECOG1: ECOG_BUSES_ROWECOG_BUSES_SMD; ECOG_BUSES_SMD
ECOG2, ECOG3: ECOG_GENERAL_ROWECOG_GENERAL_SMD; ECOG_GENERAL_SMD
JP1: .96 I2C OLED LCD; 1X04
R1, R2, R3: 47K; 0805
R4, R5, R6, R7: 10K; 0805
SD1: MICROSD
U$1, U$11: GADGETBOX_TEXT
U$2, U$16: OSHW_FILLX200_NOTEXT
U$3, U$8, U$10: GADGETBOX_SMALL
U$4, U$9: OSHW_FILLX150_NOTEXT
U$5: SENSOR; SENSOR-HJX4
U$6, U$7: LEGEND_ANALOG
U$12, U$13, U$14, U$15: LEGEND_DIO
X1: ESP-12

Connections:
3V3: ECOG.3V3, ECOG1.3V3, ECOG2.3V3, ECOG3.3V3, JP1.1, R1.2, R2.2, R3.2, R4.2, R6.2, R7.2, SD1.4, U$5.+, X1.8
A1: ECOG2.G0, U$5.AO
A2: ECOG2.G1, U$5.DO/S
GND: ECOG.GND, ECOG1.GND, ECOG2.GND, ECOG3.GND, JP1.2, R5.1, SD1.6, SD1.MT1, SD1.MT2, U$5.GND, X1.9
GPIO0/BOOTLOAD: ECOG3.G2, X1.12
unnamed: ECOG1.I2C-SCL, JP1.3
unnamed: ECOG1.I2C-SDA, JP1.4
unnamed: R4.1, X1.11
unnamed: R5.2, X1.10
unnamed: R7.1, X1.3
RESET: ECOG3.G3, R6.1, X1.1, X1.4
RX/MOSI: ECOG3.G1, X1.15
SD_!CS: ECOG.SPI-CS, R3.1, SD1.2
SD_MISO: ECOG.SPI-MISO, R1.1, SD1.7
SD_MOSI: ECOG.SPI-MOSI, R2.1, SD1.3
SD_SCK: ECOG.SPI-SCK, SD1.5
TX/MISO: ECOG3.G0, X1.16

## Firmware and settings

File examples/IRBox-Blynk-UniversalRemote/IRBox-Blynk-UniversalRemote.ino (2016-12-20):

/**************************************************************
 * This is an example for GadgetBox to create a Learning IR Remote control using Blynk
 * 
 * There are up to 10 IR commands that can be learned. Raw IR commands not supported.
 * 
 * eCogs Used:
 *       eCog107 - Remote Control - Connect to eCog B (Except for Teensy - Move to eCog D for the Teensy)
 *       eCog100 - Wifi - Connect to eCog C
 * 
 * Libraries required (Install with Library Manager):
 *       GadgetBox
 *       IRremote
 *       Blynk
 *       IRremoteESP8266 if on NodeMCU. Install manually from https://github.com/markszabo/IRremoteESP8266
 *       
 * GadgetBox Motherboards supported:      
 *       Arduino Mini Pro (Only 4 IR commands)
 *       Teensy (Be sure to install the Teensy version of IRremote)
 *       
 * Blynk App:
 *       Clone the following project in Blynk http://tinyurl.com/hjrc5pu
 *       
 * Blynk Virtual Pins:      
 *       V0:      The table to select which IR command to learn
 *       V1-V10:  Trigger a send of the IR command - connect a button or timer to send out IR command 
 *       V14:     Terminal for feedback
 *       V15:     RTC (Real Time Clock)
 *       V16:     Time Now
 *       V21-V30: Stores the IR command that is learned in the Blynk cloud
 *       V31:     LCD widget for feedback while learning
 ***************************************************************       
 * Blynk is a platform with iOS and Android apps to control
 * Arduino, Raspberry Pi and the likes over the Internet.
 * You can easily build graphic interfaces for all your
 * projects by simply dragging and dropping widgets.
 *
 *   Downloads, docs, tutorials: http://www.blynk.cc
 *   Blynk community:            http://community.blynk.cc
 *   Social networks:            http://www.fb.com/blynkapp
 *                               http://twitter.com/blynk_app
 *
 * Blynk library is licensed under MIT license
 * This example code is in public domain.
 *
 **************************************************************/
#include <GadgetBox.h>          //Install GadgetBox Library from Library Manager
#include "password.h"           //Open password.h and update your credentials

//#define SKETCHDEBUG             //Uncomment to print out debug info, uses more space... Only provides one IR command
//#define BLYNK_PRINT Serial

#if defined(CORE_TEENSY)        //Use Hardware Serial for Teensy
  #define EspSerial Serial2
  #define BLYNK_PRINT Serial
#elif defined(ARDUINO_AVR_PRO)  // or Software Serial on eCog C for Mini Pro
  #include <SoftwareSerial.h>
  SoftwareSerial EspSerial(CC0, CC1); // RX, TX (For Pro Mini)
  #define SMALL
#elif defined(ESP8266)
  #define BLYNK_PRINT Serial
  #include "GadgetBox_esp8266.h"
  const char* GBName = "IRBox";
#endif

#if defined(ESP8266)
  IRsend irsend(BC3);
  int RECV_PIN = BC2;             //Pin for IR Receiver - on eCog B by default
#else
  #include <ESP8266_Lib.h>
  #include <BlynkSimpleShieldEsp8266.h>
  #include <IRremote.h>           //Install IRremote library from Library Manager  
  // Your ESP8266 baud rate:
  #define ESP8266_BAUD 9600 
  ESP8266 wifi(&EspSerial); 
  IRsend irsend;
  int RECV_PIN = BC2;             //Pin for IR Receiver - on eCog B by default 
#endif

#include <SimpleTimer.h>
#include <TimeLib.h>
#include <WidgetRTC.h>

SimpleTimer timer;

#if !defined(SMALL)
#define FLIPDISPLAY       //Should the OLED display be flipped? Comment out if not.
String currentTime;
String currentDate;
int retries = 5;
int reconnects = 0;

#include <SPI.h>
#include <Wire.h>
#include <Adafruit_GFX.h>
#include <Adafruit_SSD1306.h>

#define OLED_RESET 99
Adafruit_SSD1306 display(OLED_RESET);

WidgetTerminal terminal(V14);
WidgetRTC rtc;

BLYNK_ATTACH_WIDGET(rtc, V15);

boolean receiveEnable = true;
int receiveTmn = 0;
#endif

IRrecv irrecv(RECV_PIN);

decode_results results;

WidgetLCD lcd(V31);

void setup()
{
  irrecv.enableIRIn(); // Start the receiver
  Serial.begin(9600);
#if defined(ESP8266)
  Wire.begin(0,SCL);
  display.begin(SSD1306_SWITCHCAPVCC, 0x3C);  // initialize with the I2C addr 0x3D (for the 128x64)
  display.clearDisplay();
  #if defined(FLIPDISPLAY)
    display.setRotation(90);
  #endif
  display.setTextSize(2);
  display.setTextColor(WHITE);
  display.setCursor(0,0);
  display.println(GBName);
  display.println("Waiting");
  display.println("For WiFi");    
  display.display();

  //startWifiManager(GBName);   //Comment this out if you want to just type credentials into password.h

  //config blynk
  if (strlen(settings.blynkToken) == 0) {
    BLYNK_ENABLED = false;
    Blynk.begin(auth, ssid, pass);  //If WifiManager did not work or is disabled then manually start Blynk with credentials from password.h
  }
  if (BLYNK_ENABLED) {
    Blynk.config(settings.blynkToken, settings.blynkServer, atoi(settings.blynkPort));
  }  

  startOTA(GBName); 
  irsend.begin();
  Wire.begin(0,SCL);
#else
  delay(10);
  EspSerial.begin(115200);
  EspSerial.println("AT+CIOBAUD=9600");
  delay(1000);
  Blynk.begin(auth, wifi, ssid, pass);
  // Set ESP8266 baud rate
  EspSerial.begin(ESP8266_BAUD);
  delay(10);  
#endif

#if !defined(SMALL)
  display.begin(SSD1306_SWITCHCAPVCC, 0x3C);  // initialize with the I2C addr 0x3D (for the 128x64)
  display.clearDisplay();
  #if defined(FLIPDISPLAY)
    display.setRotation(90);
  #endif
  display.setTextSize(2);
  display.setTextColor(WHITE);
  display.setCursor(0,0);
  display.println(GBName);
  display.println("Waiting");
  display.println("For Blynk");    
  display.display();

  while (Blynk.connect() == false) {
    // Wait until connected
    if (retries == 0){
      Serial.println("Too many failed connects, restarting...");
      reset();
    }
    else
      retries--;
  }

  // Begin synchronizing time
  rtc.begin();

  // Display digital clock every 30 seconds on Blynk app
  timer.setInterval(30000L, blynkClockDisplay);
  // Display digital clock every 1 seconds on OLED Display
  timer.setInterval(10000L, clockDisplay); 
  //This disables the receiver when sending
  receiveTmn = timer.setInterval(2000L, enableReceiver);
#endif
}

void loop()
{
#if defined(ESP8266)
  //ota loop
  ArduinoOTA.handle();
#endif
  
  Blynk.run();
#if !defined(SMALL) 
  timer.run();

  if (receiveEnable) {
    if (irrecv.decode(&results)) {
      storeCode(&results);
      irrecv.resume();
    }
  }
#endif  
}

// Storage for the recorded code
int codeType = -1; // The type of code
unsigned long codeValue; // The code value if not raw
//unsigned int rawCodes[RAWBUF]; // The durations if raw
int codeLen; // The length of the code
int toggle = 0; // The RC5/6 toggle state

// Stores the code for later playback
// Most of this code is just logging
void storeCode(decode_results *results) {
  codeType = results->decode_type;
  int count = results->rawlen;
#if !defined(SMALL)  
  //terminal.print("IR Received: ");
  if (codeType == UNKNOWN) {
  }
  else {
    if (codeType == NEC) {
        Serial.print("Received NEC: ");
        terminal.print("Received NEC: ");
      if (results->value == REPEAT) {
        return;
      }
    } 
    else if (codeType == SONY) {
        Serial.print("Received SONY: ");
        terminal.print("Received SONY: ");    
    } 
    else if (codeType == PANASONIC) {
        Serial.print("Received PANASONIC: "); 
        terminal.print("Received PANASONIC: "); 
    }
    else if (codeType == JVC) {
        Serial.print("Received JVC: ");
        terminal.print("Received JVC: ");  
    }
    else if (codeType == RC5) {
        Serial.print("Received RC5: ");
        terminal.print("Received RC5: ");   
    } 
    else if (codeType == RC6) {
        Serial.print("Received RC6: "); 
        terminal.print("Received RC6: ");     
    } 
    else {
        Serial.print("Unexpected codeType ");
        Serial.print(codeType, DEC);
        Serial.println("");  
        terminal.print("Unexpected codeType: ");     
    }
  }
    terminal.print(results->value, HEX);
    terminal.print(" length: ");
    terminal.println(results->bits);
    terminal.flush();  
    Serial.print(results->value, HEX);
    Serial.print(" length: ");
    Serial.println(results->bits);    
#endif
    lcd.print(5,1,results->value);
    lcd.print(14,1,results->bits);
    codeValue = results->value;
    codeLen = results->bits;
}

void sendCode(int repeat) {
#if !defined(SMALL)
  if (receiveEnable){
    irsend.sendNEC(codeValue,codeLen);  //Just clear the sender
    irsend.sendNEC(codeValue,codeLen);  //Just clear the sender
    irsend.sendNEC(codeValue,codeLen);  //Just clear the sender
    Serial.println("Stopping IR Receive while Sending");
    terminal.println("Stopping IR Receive while Sending");
    terminal.flush();    
  }
  receiveEnable = false;
  timer.restartTimer(receiveTmn);
#endif
  if (codeType == NEC) {
    if (repeat) {
      irsend.sendNEC(REPEAT, codeLen);
    } 
    else {
      irsend.sendNEC(codeValue, codeLen);
    }
  } 
  else if (codeType == SONY) {
    irsend.sendSony(codeValue, codeLen);
  } 
  else if (codeType == PANASONIC) {
    irsend.sendPanasonic(codeValue, codeLen);
  }
  else if (codeType == JVC) {
    irsend.sendPanasonic(codeValue, codeLen);
  }
  else if (codeType == RC5 || codeType == RC6) {
    if (!repeat) {
      // Flip the toggle bit for a new button press
      toggle = 1 - toggle;
    }
    // Put the toggle bit into the code to send
    codeValue = codeValue & ~(1 << (codeLen - 1));
    codeValue = codeValue | (toggle << (codeLen - 1));
    if (codeType == RC5) {
      irsend.sendRC5(codeValue, codeLen);
    } 
    else {
      irsend.sendRC6(codeValue, codeLen);
    }
  } 
  else if (codeType == UNKNOWN /* i.e. raw */) {
    // Assume 38 KHz
    //irsend.sendRaw(rawCodes, codeLen, 38);    Raw is disabled to save space...
  }
}

void learnIR(int rowId) {
  lcd.clear();
  lcd.print(0,0,"Waiting for IR");
  int found = 0;
  irrecv.enableIRIn();
  for(int i = 0;i<50;i++){
    if(irrecv.decode(&results)){
      storeCode(&results);
      found = 1;
      switch (rowId)
      {
        case 1:
          Blynk.virtualWrite(V0, "pick", 1);
          Blynk.virtualWrite(V21,codeType,codeValue,codeLen);
          break;
#if !defined(SKETCHDEBUG)            
        case 2:
          Blynk.virtualWrite(V0, "pick", 2);
          Blynk.virtualWrite(V22,codeType,codeValue,codeLen);
          break;
        case 3:
          Blynk.virtualWrite(V0, "pick", 3);
          Blynk.virtualWrite(V23,codeType,codeValue,codeLen);
          break;
        case 4:
          Blynk.virtualWrite(V0, "pick", 4);
          Blynk.virtualWrite(V24,codeType,codeValue,codeLen);
          break;  
#if !defined(ARDUINO_AVR_PRO)            
        case 5:
          Blynk.virtualWrite(V0, "pick", 5);
          Blynk.virtualWrite(V25,codeType,codeValue,codeLen);
          break;          
        case 6:
          Blynk.virtualWrite(V0, "pick", 6);
          Blynk.virtualWrite(V26,codeType,codeValue,codeLen);
          break;    
        case 7:
          Blynk.virtualWrite(V0, "pick", 7);
          Blynk.virtualWrite(V27,codeType,codeValue,codeLen);
          break;  
        case 8:
          Blynk.virtualWrite(V0, "pick", 8);
          Blynk.virtualWrite(V28,codeType,codeValue,codeLen);
          break;  
        case 9:
          Blynk.virtualWrite(V0, "pick", 9);
          Blynk.virtualWrite(V29,codeType,codeValue,codeLen);
          break;  
        case 10:
          Blynk.virtualWrite(V0, "pick", 10);
          Blynk.virtualWrite(V30,codeType,codeValue,codeLen);
          break;                                                                       
#endif
#endif           
        default:
          break;
      }
      lcd.print(0,0,"IR Found      ");
      break; 
    }
    delay(100);
  }
  if (!found) {
    lcd.clear(); 
    lcd.print(0,0,"IR Timeout");
  }
}

BLYNK_WRITE(V0)
{
  //Learn Mode
   String cmd = param[0].asStr();
   if (cmd == "select") {
       //row in table was selected.        
        learnIR(param[1].asInt());
   }
   if (cmd == "deselect") {
       //row in table was deselected. 
       learnIR(param[1].asInt());
   }
}

BLYNK_WRITE(V1)
{
  if(param[0].asInt()){
    Blynk.syncVirtual(V21);     
  }
}
#if !defined(SKETCHDEBUG)  
BLYNK_WRITE(V2)
{
  if(param[0].asInt()){
    Blynk.syncVirtual(V22); 
  }
}

BLYNK_WRITE(V3)
{
  if(param[0].asInt()){
    Blynk.syncVirtual(V23); 
  }
}

BLYNK_WRITE(V4)
{
  if(param[0].asInt()){
    Blynk.syncVirtual(V24); 
  }
}
#if !defined(SMALL) 
  BLYNK_WRITE(V5)
  {
    if(param[0].asInt()){
      Blynk.syncVirtual(V25); 
    }
  }

  BLYNK_WRITE(V6)
  {
    if(param[0].asInt()){
      Blynk.syncVirtual(V26); 
    }
  }
  
  BLYNK_WRITE(V7)
  {
    if(param[0].asInt()){
      Blynk.syncVirtual(V27); 
    }
  }
  
  BLYNK_WRITE(V8)
  {
    if(param[0].asInt()){
      Blynk.syncVirtual(V28); 
    }
  }

  BLYNK_WRITE(V9)
  {
    Serial.println("V9");
    if(param[0].asInt()){
      Blynk.syncVirtual(V29); 
    }
  }
  
  BLYNK_WRITE(V10)
  {
    Serial.println("V10");
    if(param[0].asInt()){
      Blynk.syncVirtual(V30); 
    }
  }
#endif
#endif 

BLYNK_WRITE(V21)
{
    codeType = param[0].asInt();
    codeValue = param[1].asInt();
    codeLen = param[2].asInt();
    sendCode(0); 
    #if !defined(SMALL)
    terminal.print("IR1 Sent at: ");
    terminal.println(currentTime);
    terminal.flush();
    #endif      
}
#if !defined(SKETCHDEBUG)  
BLYNK_WRITE(V22)
{
    codeType = param[0].asInt();
    codeValue = param[1].asInt();
    codeLen = param[2].asInt();
    sendCode(0);
    #if !defined(SMALL)
    terminal.print("IR2 Sent at: ");
    terminal.println(currentTime);
    terminal.flush();
    #endif    
}

BLYNK_WRITE(V23)
{
    codeType = param[0].asInt();
    codeValue = param[1].asInt();
    codeLen = param[2].asInt();
    sendCode(0);
    #if !defined(SMALL)
    terminal.print("IR3 Sent at: ");
    terminal.println(currentTime);
    terminal.flush();
    #endif       
}

BLYNK_WRITE(V24)
{
    codeType = param[0].asInt();
    codeValue = param[1].asInt();
    codeLen = param[2].asInt();
    sendCode(0);
    #if !defined(SMALL)
    terminal.print("IR4 Sent at: ");
    terminal.println(currentTime);
    terminal.flush();
    #endif         
}
#if !defined(SMALL) 
  BLYNK_WRITE(V25)
  {
      codeType = param[0].asInt();
      codeValue = param[1].asInt();
      codeLen = param[2].asInt();
      sendCode(0);
      terminal.print("IR5 Sent at: ");
      terminal.println(currentTime);
      terminal.flush();
  }

  BLYNK_WRITE(V26)
  {
      codeType = param[0].asInt();
      codeValue = param[1].asInt();
      codeLen = param[2].asInt();
      sendCode(0);
      terminal.print("IR6 Sent at: ");
      terminal.println(currentTime);
      terminal.flush();
  }
  
  BLYNK_WRITE(V27)
  {
      codeType = param[0].asInt();
      codeValue = param[1].asInt();
      codeLen = param[2].asInt();
      sendCode(0);
      terminal.print("IR7 Sent at: ");
      terminal.println(currentTime);
      terminal.flush();
  }
  
  BLYNK_WRITE(V28)
  {
      codeType = param[0].asInt();
      codeValue = param[1].asInt();
      codeLen = param[2].asInt();
      sendCode(0);
      terminal.print("IR8 Sent at: ");
      terminal.println(currentTime);
      terminal.flush();
  }

  BLYNK_WRITE(V29)
  {
      codeType = param[0].asInt();
      codeValue = param[1].asInt();
      codeLen = param[2].asInt();
      sendCode(0);
      sendCode(0);
      sendCode(0);
      terminal.print("IR9 Sent at: ");
      terminal.println(currentTime);
      terminal.flush();
  }

  BLYNK_WRITE(V30)
  {
      codeType = param[0].asInt();
      codeValue = param[1].asInt();
      codeLen = param[2].asInt();
      sendCode(0);
      sendCode(0);
      sendCode(0);
      terminal.print("IR10 Sent at: ");
      terminal.println(currentTime);
      terminal.flush();
  }
#endif
#endif 

// This function will run every time Blynk connection is established
BLYNK_CONNECTED() {
  //Setup the IR command table
  Blynk.virtualWrite(V0, "clr");
  Blynk.virtualWrite(V0, "add", 0, "Button", "Virtual Pin");
  Blynk.virtualWrite(V0, "add", 1, "IR1", "V1");
  #if !defined(SKETCHDEBUG)  
  Blynk.virtualWrite(V0, "add", 2, "IR2", "V2");
  Blynk.virtualWrite(V0, "add", 3, "IR3", "V3");
  Blynk.virtualWrite(V0, "add", 4, "IR4", "V4");
  #if !defined(SMALL) 
    Blynk.virtualWrite(V0, "add", 5, "IR5", "V5"); 
    Blynk.virtualWrite(V0, "add", 6, "IR6", "V6");   
    Blynk.virtualWrite(V0, "add", 7, "IR7", "V7"); 
    Blynk.virtualWrite(V0, "add", 8, "IR8", "V8"); 
    Blynk.virtualWrite(V0, "add", 9, "IR9", "V9"); 
    Blynk.virtualWrite(V0, "add", 10, "IR10", "V10");
  #endif
  #endif

#if defined(CORE_TEENSY)
  lcd.clear();
  lcd.print(0,0,"Teensy");
  lcd.print(0,1,"Connected");
#elif defined(ARDUINO_AVR_PRO)
  lcd.clear();
  lcd.print(0,0,"Mini Pro");
#elif defined(ESP8266)
  lcd.clear();
  lcd.print(0,0,"NodeMCU");
  lcd.print(0,1,"Connected");
#endif

#if !defined(SMALL)
  terminal.print(GBName);
  terminal.println(" Online");
  terminal.print(reconnects);
  terminal.println(" reconnects so far.");
  terminal.flush();

  Serial.print(reconnects);
  Serial.println(" reconnects so far.");
  if (reconnects == 4) {
    terminal.println("Too many reconnects, please stop Blynk App, wait 20 seconds, and restart.");
    terminal.println("There is a bug in the Blynk App...");
    terminal.flush();
    #if defined(ESP8266)
      restart();
    #endif
  }
  else 
    reconnects++;  

  display.clearDisplay();
  display.setRotation(90);
  display.setTextSize(2);
  display.setTextColor(WHITE);
  display.setCursor(0,0);
  display.println(GBName);
  display.println("Connected");    
  display.display(); 
#endif



  delay(4000);
  lcd.clear();
  lcd.print(0,0,"Tap a line");
  lcd.print(0,1,"to Learn IR");
}

#if !defined(SMALL)
// Utility function for digital clock display: prints preceding colon and leading 0
void printDigits(int digits)
{
  Serial.print(":");
  if (digits < 10) {
    Serial.print('0');
  }
  Serial.print(digits);
}

// Digital clock display of the time on Blynk App
void blynkClockDisplay()
{
  currentTime = String(hour()) + ":" + minute() + ":" + second();
  currentDate = String(month()) + " " + day() + " " + year();
  Serial.print("Current time: ");
  Serial.print(currentTime);
  Serial.print(" ");
  Serial.print(currentDate);
  Serial.println();

  // Send time to the App
  Blynk.virtualWrite(V16, currentTime);
  // Send date to the App
  Blynk.virtualWrite(V17, currentDate);  
}

// Digital clock display of the time on OLED display
void clockDisplay()
{
  currentTime = String(hour()) + ":" + minute() + ":" + second();
  currentDate = String(month()) + " " + day() + " " + year();

  display.clearDisplay();
  display.setCursor(0,0);
  display.println(GBName);
  if (Blynk.connected())
    display.println("Connected");    
  else
    display.println("Offline");
  display.println(currentTime);   
  display.print(currentDate);  
  display.display();   
}

void enableReceiver()
{
  if (!receiveEnable) {
    receiveEnable = true;
    irrecv.enableIRIn();
//    irrecv.resume();
    Serial.println("IR Receive Enabled.");    
    terminal.println("IR Receive Enabled.");
    terminal.flush();
  }
}
#endif

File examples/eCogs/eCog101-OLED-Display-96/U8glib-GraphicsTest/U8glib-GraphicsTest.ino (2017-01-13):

/**************************************************************
 * Use this sketch to test .96" OLED Display eCog
 * 
 * Once you verify that the display works take a look at the other U8glib examples sketches included with the library
 * 
 * eCogs Used:
 *       eCog101 - .96" OLED Display - Connect to any eCog location
 * 
 * Libraries required (Install with Library Manager):
 *       GadgetBox
 *       U8glib
 *       
 * GadgetBox Motherboards supported:      
 *       Arduino Mini Pro
 *       
 **************************************************************/
/*

  GraphicsTest.pde
  
  >>> Before compiling: Please remove comment from the constructor of the 
  >>> connected graphics display (see below).
  
  Universal 8bit Graphics Library, https://github.com/olikraus/u8glib/
  
  Copyright (c) 2012, olikraus@gmail.com
  All rights reserved.

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
  THIS SOFTWARE IS PROVIDED BY THE COPYRIGHT HOLDERS AND 
  CONTRIBUTORS "AS IS" AND ANY EXPRESS OR IMPLIED WARRANTIES, 
  INCLUDING, BUT NOT LIMITED TO, THE IMPLIED WARRANTIES OF 
  MERCHANTABILITY AND FITNESS FOR A PARTICULAR PURPOSE ARE 
  DISCLAIMED. IN NO EVENT SHALL THE COPYRIGHT HOLDER OR 
  CONTRIBUTORS BE LIABLE FOR ANY DIRECT, INDIRECT, INCIDENTAL, 
  SPECIAL, EXEMPLARY, OR CONSEQUENTIAL DAMAGES (INCLUDING, BUT 
  NOT LIMITED TO, PROCUREMENT OF SUBSTITUTE GOODS OR SERVICES; 
  LOSS OF USE, DATA, OR PROFITS; OR BUSINESS INTERRUPTION) HOWEVER 
  CAUSED AND ON ANY THEORY OF LIABILITY, WHETHER IN CONTRACT, 
  STRICT LIABILITY, OR TORT (INCLUDING NEGLIGENCE OR OTHERWISE) 
  ARISING IN ANY WAY OUT OF THE USE OF THIS SOFTWARE, EVEN IF 
  ADVISED OF THE POSSIBILITY OF SUCH DAMAGE.  


*/

#include <GadgetBox.h>
#include "U8glib.h"

// setup u8g object, please remove comment from one of the following constructor calls
// IMPORTANT NOTE: The following list is incomplete. The complete list of supported 
// devices with all constructor calls is here: https://github.com/olikraus/u8glib/wiki/device
//U8GLIB_SSD1306_128X64 u8g(U8G_I2C_OPT_NONE|U8G_I2C_OPT_DEV_0);	// I2C / TWI 
U8GLIB_SSD1306_128X64 u8g(U8G_I2C_OPT_DEV_0|U8G_I2C_OPT_NO_ACK|U8G_I2C_OPT_FAST);	// Fast I2C / TWI 
//U8GLIB_SSD1306_128X64 u8g(U8G_I2C_OPT_NO_ACK);	// Display which does not send AC

void u8g_prepare(void) {
  u8g.setFont(u8g_font_6x10);
  u8g.setFontRefHeightExtendedText();
  u8g.setDefaultForegroundColor();
  u8g.setFontPosTop();
}

void u8g_box_frame(uint8_t a) {
  u8g.drawStr( 0, 0, "drawBox");
  u8g.drawBox(5,10,20,10);
  u8g.drawBox(10+a,15,30,7);
  u8g.drawStr( 0, 30, "drawFrame");
  u8g.drawFrame(5,10+30,20,10);
  u8g.drawFrame(10+a,15+30,30,7);
}

void u8g_disc_circle(uint8_t a) {
  u8g.drawStr( 0, 0, "drawDisc");
  u8g.drawDisc(10,18,9);
  u8g.drawDisc(24+a,16,7);
  u8g.drawStr( 0, 30, "drawCircle");
  u8g.drawCircle(10,18+30,9);
  u8g.drawCircle(24+a,16+30,7);
}

void u8g_r_frame(uint8_t a) {
  u8g.drawStr( 0, 0, "drawRFrame/Box");
  u8g.drawRFrame(5, 10,40,30, a+1);
  u8g.drawRBox(50, 10,25,40, a+1);
}

void u8g_string(uint8_t a) {
  u8g.drawStr(30+a,31, " 0");
  u8g.drawStr90(30,31+a, " 90");
  u8g.drawStr180(30-a,31, " 180");
  u8g.drawStr270(30,31-a, " 270");
}

void u8g_line(uint8_t a) {
  u8g.drawStr( 0, 0, "drawLine");
  u8g.drawLine(7+a, 10, 40, 55);
  u8g.drawLine(7+a*2, 10, 60, 55);
  u8g.drawLine(7+a*3, 10, 80, 55);
  u8g.drawLine(7+a*4, 10, 100, 55);
}

void u8g_triangle(uint8_t a) {
  uint16_t offset = a;
  u8g.drawStr( 0, 0, "drawTriangle");
  u8g.drawTriangle(14,7, 45,30, 10,40);
  u8g.drawTriangle(14+offset,7-offset, 45+offset,30-offset, 57+offset,10-offset);
  u8g.drawTriangle(57+offset*2,10, 45+offset*2,30, 86+offset*2,53);
  u8g.drawTriangle(10+offset,40+offset, 45+offset,30+offset, 86+offset,53+offset);
}

void u8g_ascii_1() {
  char s[2] = " ";
  uint8_t x, y;
  u8g.drawStr( 0, 0, "ASCII page 1");
  for( y = 0; y < 6; y++ ) {
    for( x = 0; x < 16; x++ ) {
      s[0] = y*16 + x + 32;
      u8g.drawStr(x*7, y*10+10, s);
    }
  }
}

void u8g_ascii_2() {
  char s[2] = " ";
  uint8_t x, y;
  u8g.drawStr( 0, 0, "ASCII page 2");
  for( y = 0; y < 6; y++ ) {
    for( x = 0; x < 16; x++ ) {
      s[0] = y*16 + x + 160;
      u8g.drawStr(x*7, y*10+10, s);
    }
  }
}

void u8g_extra_page(uint8_t a)
{
  if ( u8g.getMode() == U8G_MODE_HICOLOR || u8g.getMode() == U8G_MODE_R3G3B2) {
    /* draw background (area is 128x128) */
    u8g_uint_t r, g, b;
    b = a << 5;
    for( g = 0; g < 64; g++ )
    {
      for( r = 0; r < 64; r++ )
      {
	u8g.setRGB(r<<2, g<<2, b );
	u8g.drawPixel(g, r);
      }
    }
    u8g.setRGB(255,255,255);
    u8g.drawStr( 66, 0, "Color Page");
  }
  else if ( u8g.getMode() == U8G_MODE_GRAY2BIT )
  {
    u8g.drawStr( 66, 0, "Gray Level");
    u8g.setColorIndex(1);
    u8g.drawBox(0, 4, 64, 32);    
    u8g.drawBox(70, 20, 4, 12);
    u8g.setColorIndex(2);
    u8g.drawBox(0+1*a, 4+1*a, 64-2*a, 32-2*a);
    u8g.drawBox(74, 20, 4, 12);
    u8g.setColorIndex(3);
    u8g.drawBox(0+2*a, 4+2*a, 64-4*a, 32-4*a);
    u8g.drawBox(78, 20, 4, 12);
  }
  else
  {
    u8g.drawStr( 0, 12, "setScale2x2");
    u8g.setScale2x2();
    u8g.drawStr( 0, 6+a, "setScale2x2");
    u8g.undoScale();
  }
}


uint8_t draw_state = 0;

void draw(void) {
  u8g_prepare();
  switch(draw_state >> 3) {
    case 0: u8g_box_frame(draw_state&7); break;
    case 1: u8g_disc_circle(draw_state&7); break;
    case 2: u8g_r_frame(draw_state&7); break;
    case 3: u8g_string(draw_state&7); break;
    case 4: u8g_line(draw_state&7); break;
    case 5: u8g_triangle(draw_state&7); break;
    case 6: u8g_ascii_1(); break;
    case 7: u8g_ascii_2(); break;
    case 8: u8g_extra_page(draw_state&7); break;
  }
}

void setup(void) {

  // flip screen, if required
  //u8g.setRot180();

}

void loop(void) {
  
  // picture loop  
  u8g.firstPage();  
  do {
    draw();
  } while( u8g.nextPage() );
  
  // increase the state
  draw_state++;
  if ( draw_state >= 9*8 )
    draw_state = 0;
  
  // rebuild the picture after some delay
  //delay(150);

}

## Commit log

2016-03-25 Gadget-Box Derived from Firefly-Box
    [Gadget-Box.brd, Gadget-Box.sch, eCog_Buses_Template.brd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]
2016-03-28 Change the spacings to fit enclosure and headers to eCogs.
    [Gadget-Box.brd, Gadget-Box.sch]
2016-03-28 Update library and templates for surface mount pin headers.
    [eCog_Buses_Template.brd, eCog_Buses_Template.sch, eCog_General_Template.brd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]
2016-03-28 Update pin names for the buses
    [eCog_Buses_Template.brd, eCog_Buses_Template.sch]
2016-04-22 New eCogs
    [eCog0_Blank.brd, eCog0_Blank.sch, eCog105_Joystick_PS2.brd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]
2016-06-27 Latest updated to V1.4
    [Gadget-Box-atmega32u4.brd, Gadget-Box-atmega32u4.sch, Gadget-Box.brd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]
2016-06-28 Updated the legend on the silkscreen
    [Gadget-Box.brd]
2016-06-29 Added "To get started" to bottom silkscreen
    [Gadget-Box.brd]
2016-06-29 Remote Control eCog
    [eCog107_Remote_Control.brd, eCog107_Remote_Control.sch]
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2016-06-29 Added parts to attributes for BOM
    [eCog100_ESP8266_Wifi.brd, eCog100_ESP8266_Wifi.sch, eCog101_I2C_TFT_.96.brd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]
2016-06-29 Added Box text to silkscreen
    [eCog100_ESP8266_Wifi.brd, eCog101_I2C_TFT_.96.brd, eCog102_uSD.brd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]
2016-06-29 Moved templates into folder
    [eCog_Analog_Template.brd, eCog_Analog_Template.sch, eCog_Buses_Template.brd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]
2016-06-29 made the first panel of eCogs
    [pCog100_Wifi_Sensor_uSD_TFT.brd, pCog100_Wifi_Sensor_uSD_TFT.sch]
2016-06-30 A couple more eCog panels
    [pCog101_Wifi_Remote_BLED.brd, pCog101_Wifi_Remote_BLED.sch, pCog102_Wifi_PSPJoy_BLED_TFT.brd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]
2016-06-30 Update all of the Fonts and graphics
    [eCog0_Blank.brd, eCog100_ESP8266_Wifi.brd, eCog101_I2C_TFT_.96.brd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]
2016-06-30 Fix a trace on the Sensor eCog that went through cutout.
    [eCog103_Sensor.brd, pCog100_Wifi_Sensor_uSD_TFT.brd]
2016-07-06 Version 1.6 - Changed Crystal to 8Mhz and 16Mhz footprint.
    Updated silkscreen
    [Gadget-Box.brd, Gadget-Box.sch]
2016-07-06 GadgetBox - Version 1.7
    7/6/2016 V1.6 GadgetBox
    Changed size of board to fit white cases. 93.5x53.5
    Added voltage divider to allow capturing battery power on pin D5.
    Added all BOM info.
    Rerouted 3.3v and GND to provide better paths.
    Moved location of compontents for the BH silkscreen and the new board
    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
    [Gadget-Box.brd, Gadget-Box.sch]
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2016-07-11 GadgetBox V1.7
    Move the On/Off locations
    [Gadget-Box.brd]
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2016-08-10 GB Mini Pro V1.2
    [Gadget-Box-mini-pro.brd, Gadget-Box-mini-pro.sch]
2016-08-10 Fixed the backwards rx and tx lines.
    [Gadget-Box-mini-pro.brd, Gadget-Box-mini-pro.sch]
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2016-08-10 V1.2
    Moved JST battery connector
    [Gadget-Box-mini-pro.brd, Gadget-Box-mini-pro.sch]
2016-08-10 V1.2.1
    Fixed a problem with A0-A3
    [Gadget-Box-mini-pro.brd, Gadget-Box-mini-pro.sch]
2016-08-16 All the 2.0 updates
    [Gadget-Box-mini-pro.brd, Gadget-Box-mini-pro.sch, eCog100_ESP8266_Wifi.brd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]
2016-09-29 Changed the pins to support PWM in correct locations
    [Gadget-Box-PiZero.brd, Gadget-Box-PiZero.sch]
2016-09-29 Moved pi zero over 2mm to make room for SD card.
    [Gadget-Box-PiZero.brd]
2016-09-30 Removed all charging circuits.
    [Gadget-Box-PiZero.brd, Gadget-Box-PiZero.sch]
2016-09-30 Fixed silkscreen
    [Gadget-Box-PiZero.brd, text_A.brd, text_B.brd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]
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2016-09-30 Add a second, cheaper crystal option.
    [Gadget-Box-328pb.brd, Gadget-Box-328pb.sch]
2016-09-30 Fixed problem with silkscreen
    [Gadget-Box-328pb.brd, text_A.brd]
2016-09-30 Add resistor to prevent 3.3V from FTDI Module.
    [Gadget-Box-328pb.brd, Gadget-Box-328pb.sch]
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2016-10-03 Updated silkscreen and BOM for GadgetBox-ESP8266
    [Gadget-Box-ESP8266.brd, Gadget-Box-ESP8266.sch, text_A.brd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]
2016-10-03 Redid the Mini Pro Clone with better routing.
    [Gadget-Box-mini-pro.brd, GadgetBox-Mini-Pro-Clone.brd, GadgetBox-Mini-Pro-Clone.sch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]
2016-10-03 Added a new version that only uses modules.
    [Gadget-Box-teensy-modules.brd, Gadget-Box-teensy-modules.sch]
2016-10-04 Removed BAT from silkscreen
    [Gadget-Box-PiZero.brd]
2016-10-05 Updated Li-ON module and moved battery connector to top.
    [GadgetBox-Mini-Pro-Clone-Modules.brd, GadgetBox-Mini-Pro-Clone-Modules.sch]
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2016-10-06 Removed RST and 5V - Fixed silkscreen
    [GadgetBox-Mini-Pro-Clone-Modules.brd, GadgetBox-Mini-Pro-Clone-Modules.sch, text_A.brd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]
2016-10-06 Fixed charging circuit
    [Gadget-Box-teensy-modules.brd, Gadget-Box-teensy-modules.sch]
2016-10-06 Added battery cable cutout
    [Gadget-Box-teensy-modules.brd]
2016-10-06 Fixed Silkscreen - Pizero
    [Gadget-Box-PiZero.brd, Gadget-Box-PiZero.sch, text_All.brd]
2016-10-06 Changed Version text - Mini Pro
    [GadgetBox-Mini-Pro-Clone-Modules.brd]
2016-10-06 Not ready - needs a 3.3V power supply.
    [Gadget-Box-ESP8266-Modules.brd, Gadget-Box-ESP8266-Modules.sch]
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2016-10-07 Add battery wire cutout.
    [Gadget-Box-PiZero.brd]
2016-10-12 Update Remote Control Design
    Put the transmit PWM pin on XC4 for greater compatibility.
    [eCog107_Remote_Control.brd, eCog107_Remote_Control.sch]
2016-10-12 Updated to latest eCog Library
    [eCog0_Blank.brd, eCog0_Blank.sch, eCog100_ESP8266_Wifi.brd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]
2016-10-12 Redid P101
    Using Through hole and different arrangement
    [pCog101_Wifi_Remote_BLED.brd, pCog101_Wifi_Remote_BLED.sch, pCog101_Wifi_Remote_TFT.brd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]
2016-10-12 Changed the USB connector per Seeed request.
    [Gadget-Box-328pb.brd, Gadget-Box-328pb.sch]
2016-10-12 Flipped the sensor around to fit in boxes with modules in the middle.
    [eCog103_Sensor.brd, eCog103_Sensor.sch]
2016-10-12 pCog for Sensor Version 1.1
    [pCog100_Wifi_Sensor_TFT.brd, pCog100_Wifi_Sensor_TFT.sch, pCog100_Wifi_Sensor_uSD_TFT.sch]
2016-10-12 Added + and - to silkscreen for display eCog
    [pCog101_Wifi_Remote_TFT.brd, pCog101_Wifi_Remote_TFT.sch]
2016-10-12 Fix silkscreen
    [eCog101_I2C_TFT_.96.brd]
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2016-10-14 Pi RGB Matrix eCog
    [eCog116_Pi_RGB_Matrix.brd, eCog116_Pi_RGB_Matrix.sch]
2016-10-14 pCog103 for Barcode Genie
    [pCog103_Wifi_Keyboard_TFT.brd, pCog103_Wifi_Keyboard_TFT.sch]
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2016-10-27 Fix some text
    [GadgetBox-Mini-Pro-Clone-Modules.sch]
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2016-10-28 Move hardware to another Git, this is for the Arduino Library now.
    [Gadget-Box-328pb.brd, Gadget-Box-328pb.sch, Gadget-Box-ESP8266-Modules.brd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]
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2016-12-06 New release with NodeMCU pin fix
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2016-12-20 Handle the Blynk restart bug.
    [IRBox-Blynk-UniversalRemote.ino]
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2016-12-30 Fix for pin locations.

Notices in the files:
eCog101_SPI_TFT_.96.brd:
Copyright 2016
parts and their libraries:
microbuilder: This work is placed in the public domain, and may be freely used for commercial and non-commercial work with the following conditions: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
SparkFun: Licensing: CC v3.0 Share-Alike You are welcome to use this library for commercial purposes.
